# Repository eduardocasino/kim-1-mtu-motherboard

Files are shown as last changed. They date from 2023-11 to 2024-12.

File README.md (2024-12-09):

# KIM-1 Motherboard for MTU Cards

## **WARNING**

**ALTHOUGH THE CARDS HAVE BEEN TESTED NOW, THERE MAY BE MORE ERRORS. USE AT YOUR OWN RISK!!!**

If you ordered the first revision PCB, please see the "Rev. 1 Fix" section below.

If you ordered earlier revisions of the aux cards (RS-232 and USB), please see the "Aux. Cards Fix" section below. 

## **UPDATE**

There is now a third auxiliary card option, for connecting the KIM-1 terminal wirelessly using an ESP8266. This new board is not affected by the problems referred above.

This card requires to transfer its firmware to the ESP8266. [Please, see the set up instructions here](https://github.com/eduardocasino/kim-1-mtu-motherboard/blob/main/kim-1-aux-card-esp/README.md)

## About

Welcome to my KIM-1 Motherboardfor MTU cards repository.

This board follows the MTU standard for the KIM-1 expansion and application buses and enables to connect up to five cards, like the [K-1008](https://github.com/eduardocasino/k-1008-visable-memory-card-replica). All the CPU lines are buffered. Additionally, all signals of the KIM-1 ports are replicated on corresponding edge connectors to allow further expansions.

Two audio jacks allow for cassette deck connection and two optional daughterboards provide IEC and RS-232 or USB serial connections, and also a connector compatible with Corsham's SD Shield.

The MTU bus connects 1 to 1 to the KIM-1 expansion connector with the exception of pins 2,3, 16, 17, 18, 19, 20 and X, because MTU boards use some of these pins for power and expanded 18 bit address bus (See page 33 of the [MTU Fall 1980 6502 Peripherals and Software catalog](hhttp://retro.hansotten.nl/6502-sbc/mtu/) Lines 19 and 20 are connected to pins J (K7) and K (DECODE ENABLE) of the KIM-1 application connector, respectively. Those two signals can be limited to just the first or the first and second connectors by opening some jumpers.

A five screw terminal block provides power connections for both the KIM-1 (GND, +5V and +12V regulated) and the expansion boards (+7.5V and +16V unregulated). 

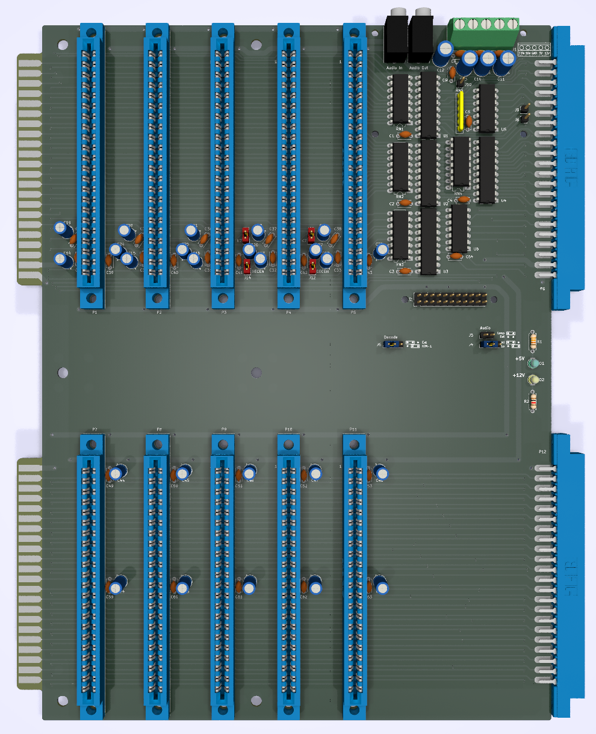
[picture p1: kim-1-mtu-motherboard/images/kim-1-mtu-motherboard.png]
components

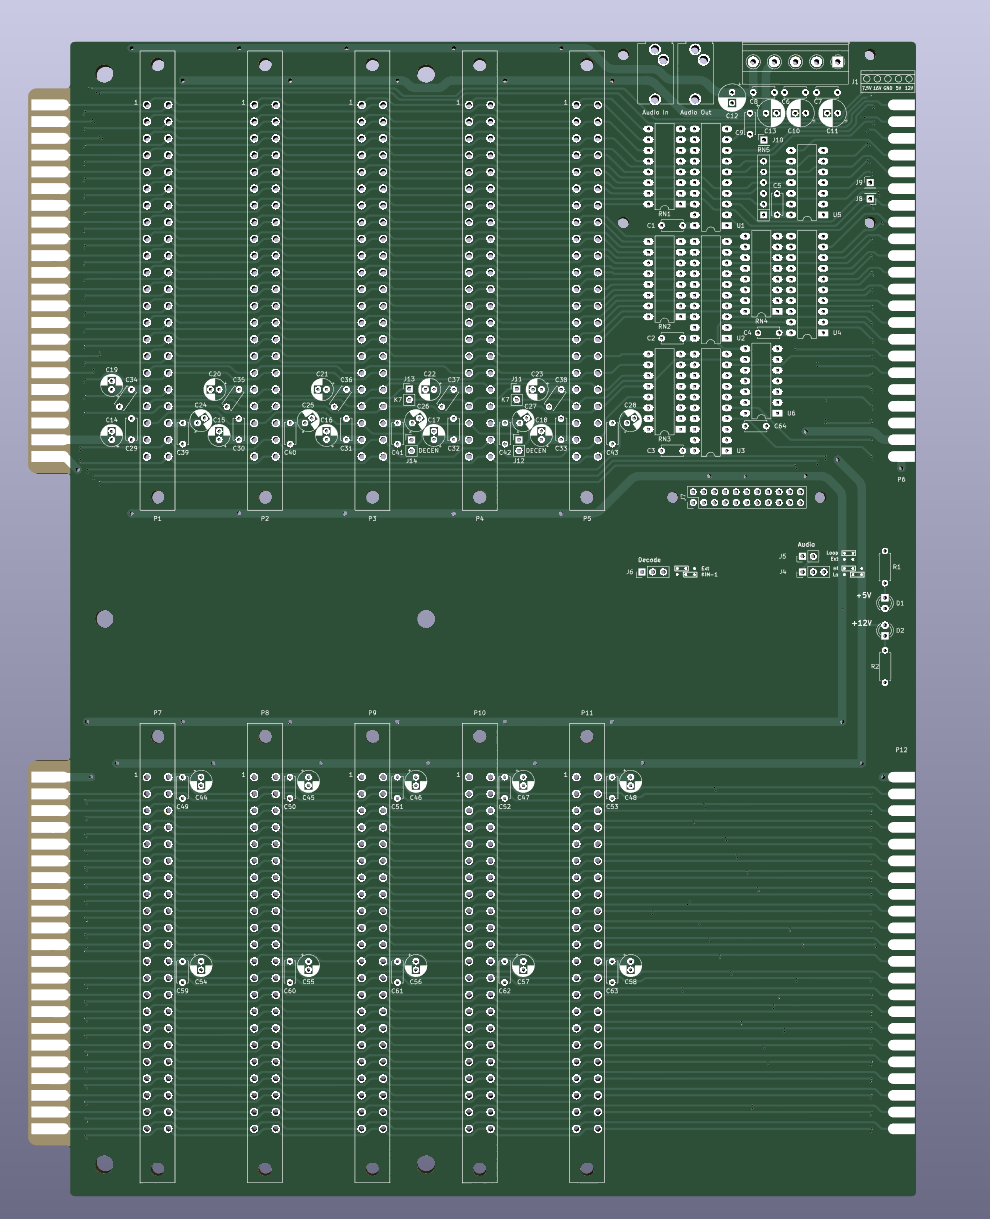
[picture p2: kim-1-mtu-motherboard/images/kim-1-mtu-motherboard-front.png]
front

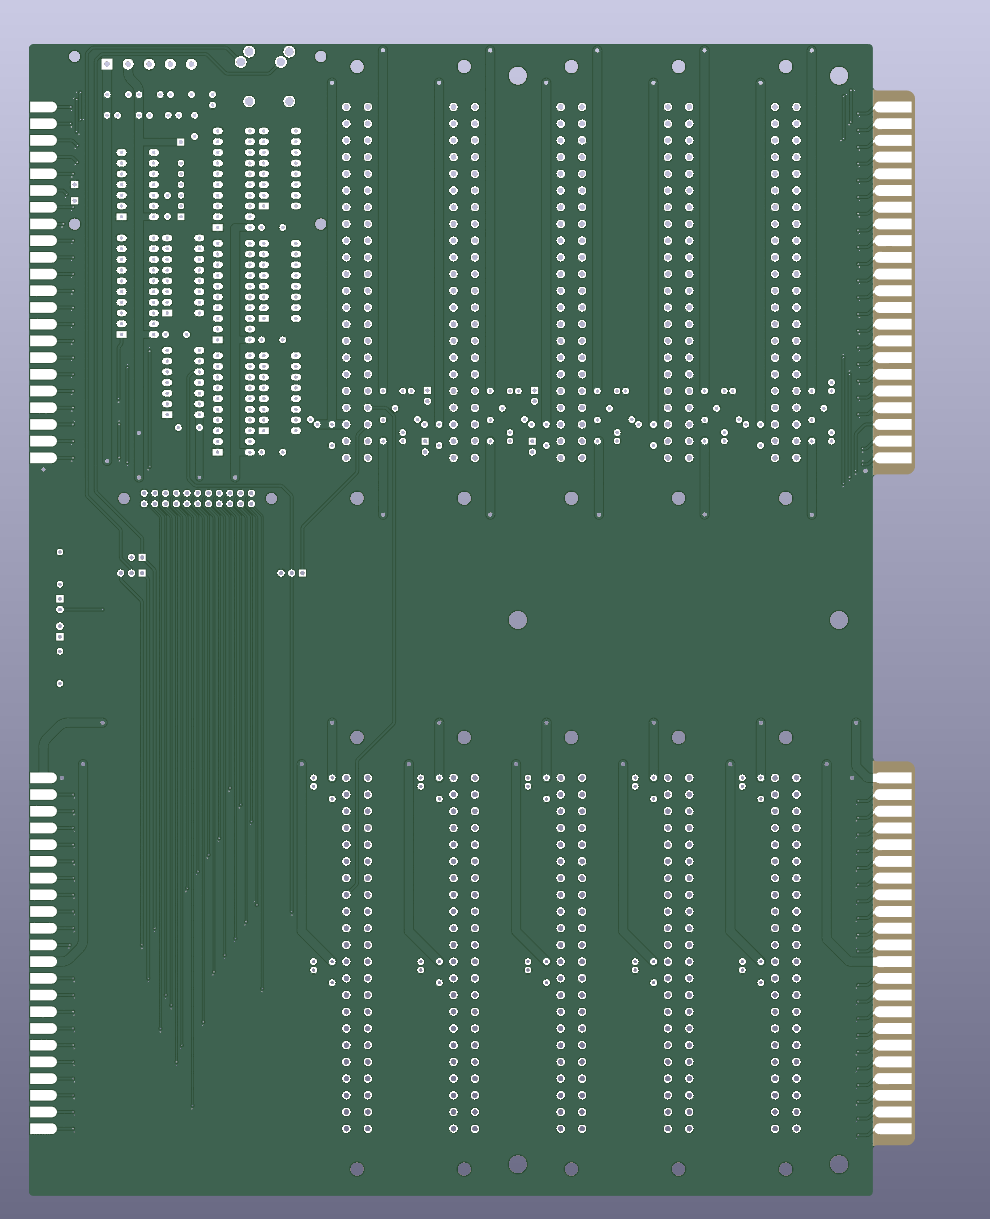
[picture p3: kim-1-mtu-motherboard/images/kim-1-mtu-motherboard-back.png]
back


Detail of the two auxiliary boards:
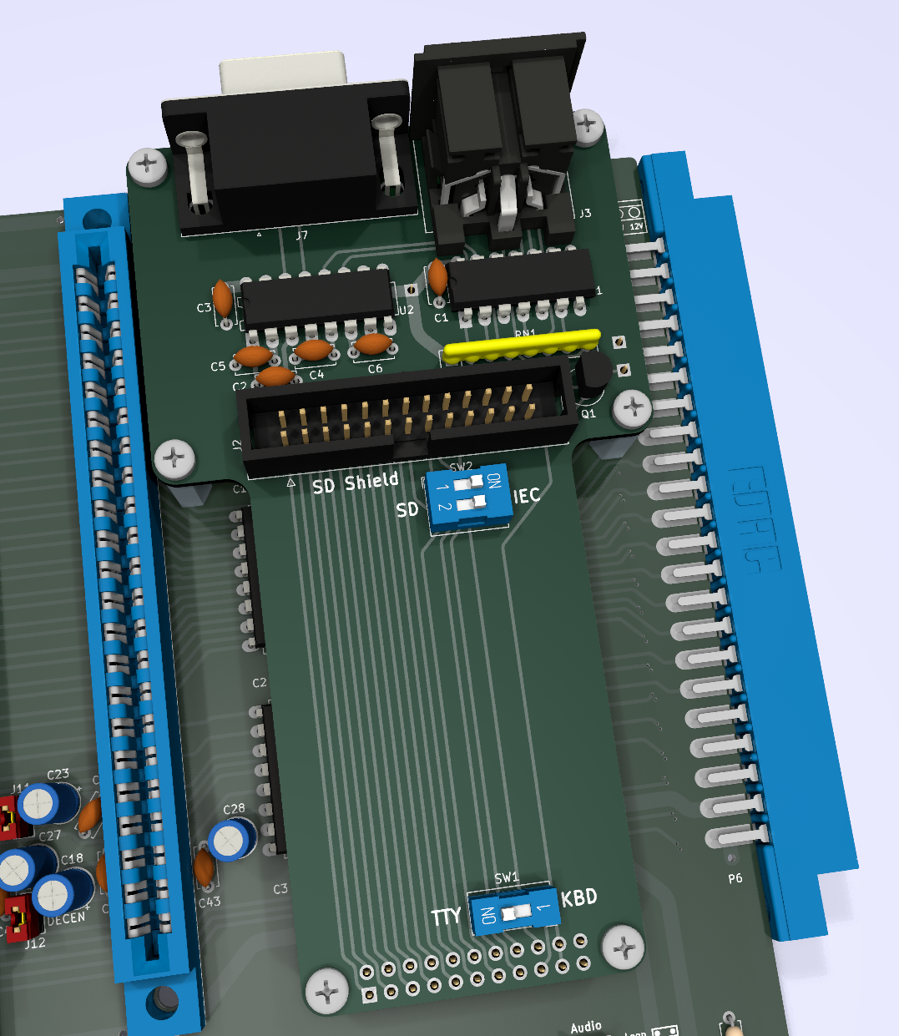
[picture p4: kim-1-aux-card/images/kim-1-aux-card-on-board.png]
rs232

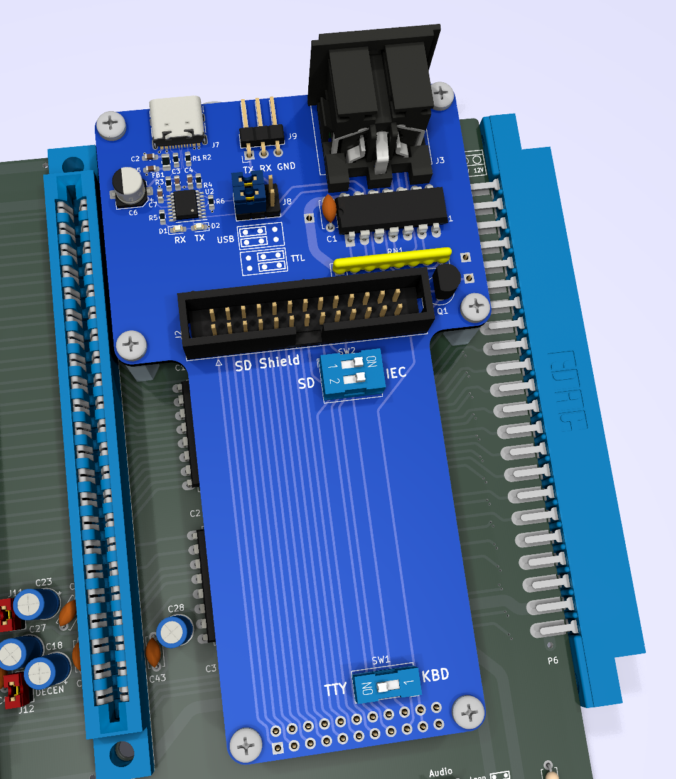
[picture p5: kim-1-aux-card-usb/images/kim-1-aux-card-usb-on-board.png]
usb


This is how an example setup with one K-1008 board and a [RAM/ROM expansion card](https://github.com/eduardocasino/kim-1-mtu-ram-rom) would look like:

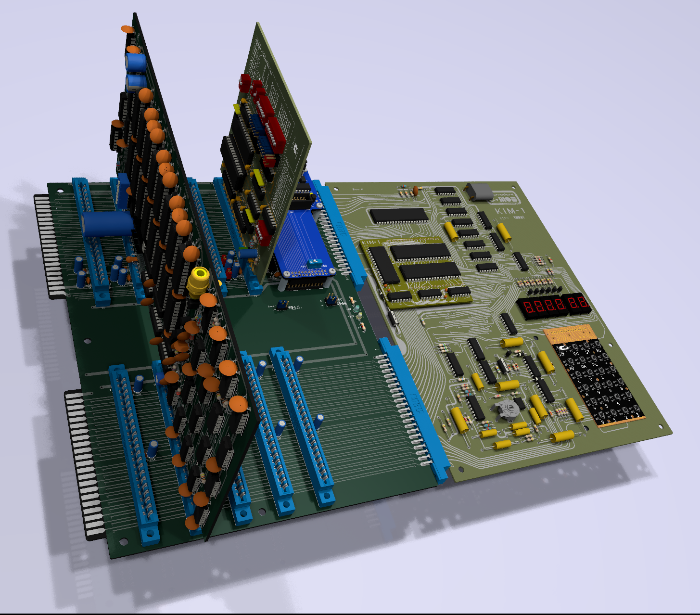
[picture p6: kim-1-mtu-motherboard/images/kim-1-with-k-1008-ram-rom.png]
setup


**NOTE**: [This expansion board is a much simpler option](https://github.com/eduardocasino/kim-1-mtu-expansion-card) if you just need to connect some MTU cards. Those are engineered so they put less than 1 TTL load on the CPU buses, so no buffering is really needed. Why the buffering, then? Well, just for fun.

## Licensing

This is a personal project that I am sharing in case it is of interest to any retrocomputing enthusiast and all the information in this repository is provided "as is", without warranty of any kind. I am not liable for any damages that may occur, whether it be to individuals, objects, KIM-1 computers, kittens or any other pets.



This work is licensed under a [Creative Commons Attribution-ShareAlike 4.0 International License](http://creativecommons.org/licenses/by-sa/4.0/).

See the LICENSE.md file for details.

## Rev. 1 Fix

If you tried to build revision 1 of this board, you found out that it does not work (See [Issue #2](https://github.com/eduardocasino/kim-1-mtu-motherboard/issues/2))

You can [install this simple PCB](https://github.com/eduardocasino/kim-1-mtu-motherboard/rev-1-fix) or, alternatively, perform this bodge on the back of the PCB:

Using a cutter, carefully cut these two spokes at pin 19 of U4:

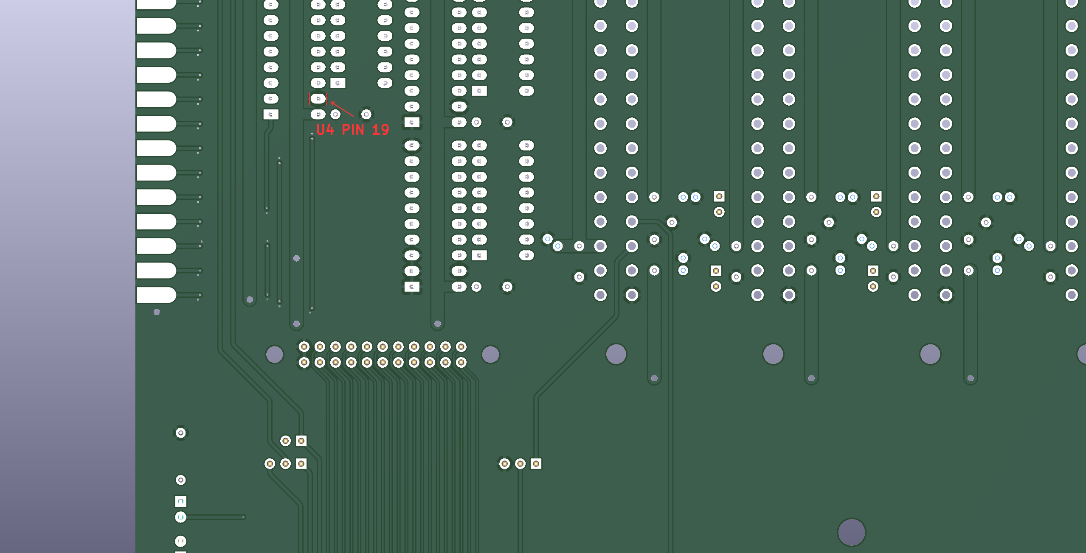
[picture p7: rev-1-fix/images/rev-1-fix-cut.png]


Grab a 14 pin IC socket with flat pins. Bend pins 1,2,3,7 and 14 outwards and cut the rest.

Solder wires to the pins as per this image:

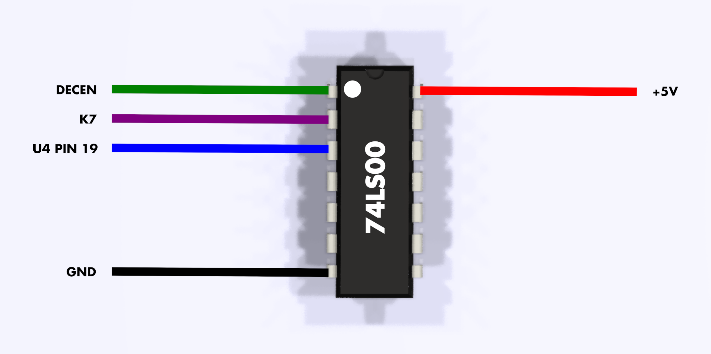
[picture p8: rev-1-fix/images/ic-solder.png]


Cover the back of the socket with non conductive tape. Attach the wires to these spots on the motherboard:

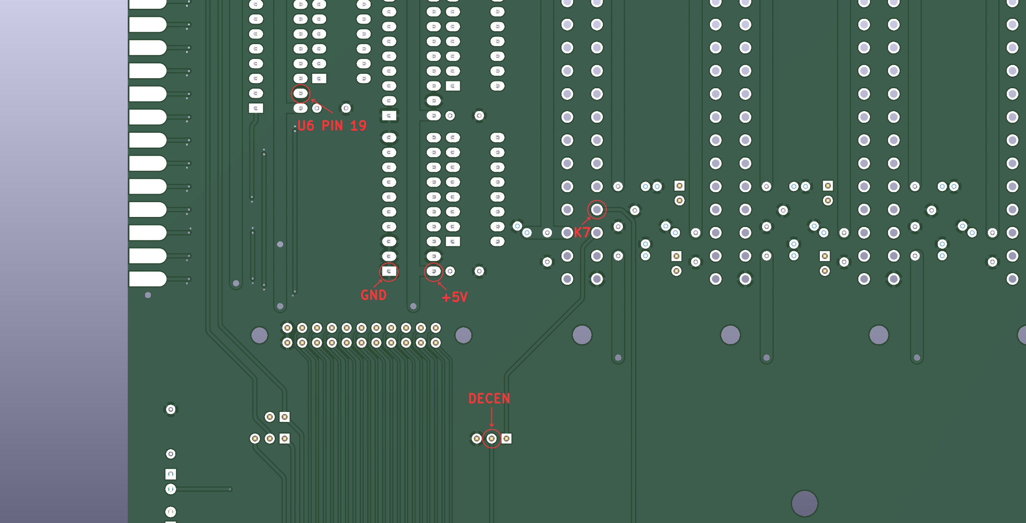
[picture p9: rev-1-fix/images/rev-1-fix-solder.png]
step2


Place a 74LS00 in the socket (check the orientation!) and fix evrything to the PCB using some tape, like in this image. I took K7 from another pin, but it is all the same:

step2

## Aux. Cards Fix

If you tried to build earlier revisions of the auxiliary boards (both RS-232 and USB), you may have found out that they do not work with Corsham's SD Shield, although they work fine with IEC disks (See [Issue #3](https://github.com/eduardocasino/kim-1-mtu-motherboard/issues/3))

If you need them to work with the SD Shield, you can perform this simple fix. **WARNING: Doing so, the cards will no longer work with IEC disks**

The fix is the same for both cards. Using a cutter, carefully cut these two tracks:

aux-card-fix

## Changelog
#### 17/02/2024
* Release Rev. 3 (fixes the auxiliary cards, the motherboard is unchanged)
* IEC socket footprint also supports Commodore-style sockets
* Add instructions to fix original auxiliary boards so they work with IEC disks.

#### 21/01/2024
* Release Rev. 2
* Add instructions to fix Rev. 1 boards.

#### 03/01/2024
* Minor silkscreen update

#### 02/01/2024
* Disable data bus transceiver when DECEN or K7 are active (low)

## Acknowledgements

* Hans Otten and his [Retro Computing blog](http://retro.hansotten.nl/). Documentation of MTU's line of hardware expansions for the KIM-1

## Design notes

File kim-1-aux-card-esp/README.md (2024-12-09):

## Wireless terminal board

This design is based on a setup by Ryan Roth, mentioned in this [Google Groups thread](https://groups.google.com/g/pal6502/c/w8N0uSgJXQY), and the ESP8266 needs to be [programmed with his firmware](https://github.com/ryaneroth/ESP8266-SerialTelnet). For convenience, I keep a [copy of his repo here](https://github.com/eduardocasino/ESP8266-SerialTelnet).

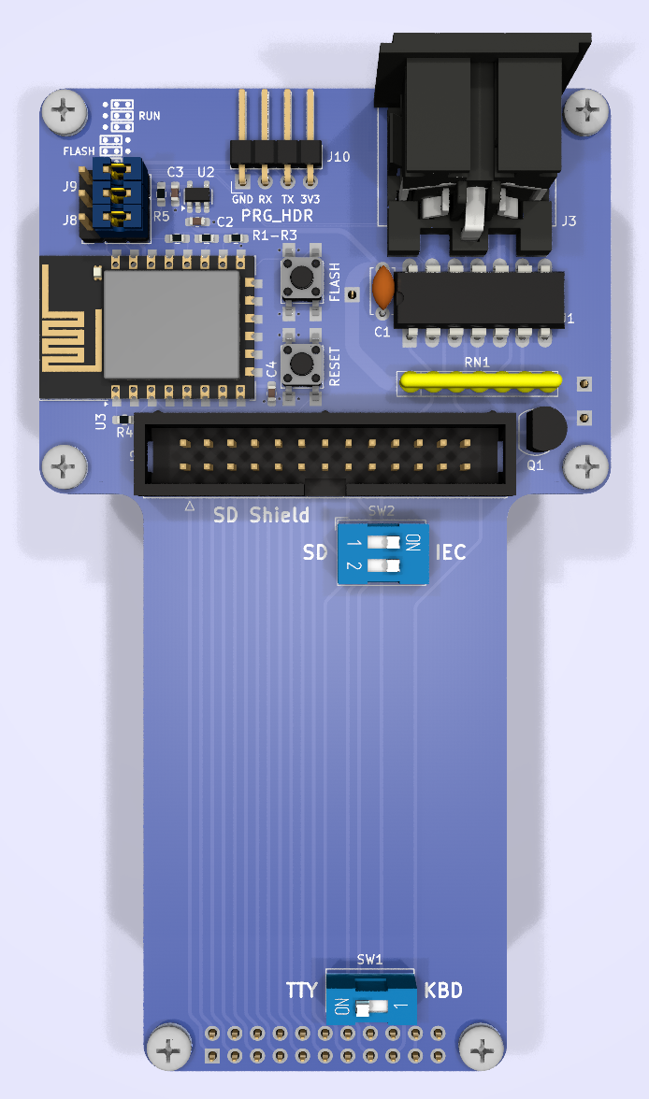
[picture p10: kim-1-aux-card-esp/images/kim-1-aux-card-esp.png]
WiFi auxiliary board


## Firmware install instructions

1. Download and install the latest **Arduino IDE 2.X (preferred) or 1.6.X** from [https://www.arduino.cc/en/Main/Software](https://www.arduino.cc/en/Main/Software)

2. Install **ESP8266** Arduino support using Boards Manager: [https://github.com/esp8266/Arduino#installing-with-boards-manager](https://github.com/esp8266/Arduino#installing-with-boards-manager)

    ***Only*** for IDE 1.6.X, force install version >= 2.4.0. Replace package URL with: [https://github.com/esp8266/Arduino/releases/download/2.4.0-rc1/package_esp8266com_index.json](https://github.com/esp8266/Arduino/releases/download/2.4.0-rc1/package_esp8266com_index.json)

3. Install Install the following libraries:
    * WifiManager: [https://github.com/tzapu/WiFiManager#install-through-library-manager](https://github.com/tzapu/WiFiManager#install-through-library-manager)

4. Put the three bridges in the "**FLASH**" position and connect the board to your computer using an USB to serial adapter.

5. Select board `Generic ESP8266Module`

6. Upload the Sketch contained in `telnetserver` folder from the [ESP8266-SerialTelnet](https://github.com/eduardocasino/ESP8266-SerialTelnet) repo.

7. The moment the `Connecting...` message appears in the console, press the "**RESET**" button and, while holding it", press momentarily the "**FLASH**" button. Then, release the "**RESET**" button. Wait until the sketch is uploaded.

8. Connect to the ESP8266 WiFi network and go to "http://192.168.4.1". Configure connection to your AP, set password, then switch back to your local wifi

9. Disconnect the card and put the bridges back to the "**RUN**" position. Now, you can install it into the motherboard.

10. Connect to the ESP8266 using a Telnet client. Set local echo to off.

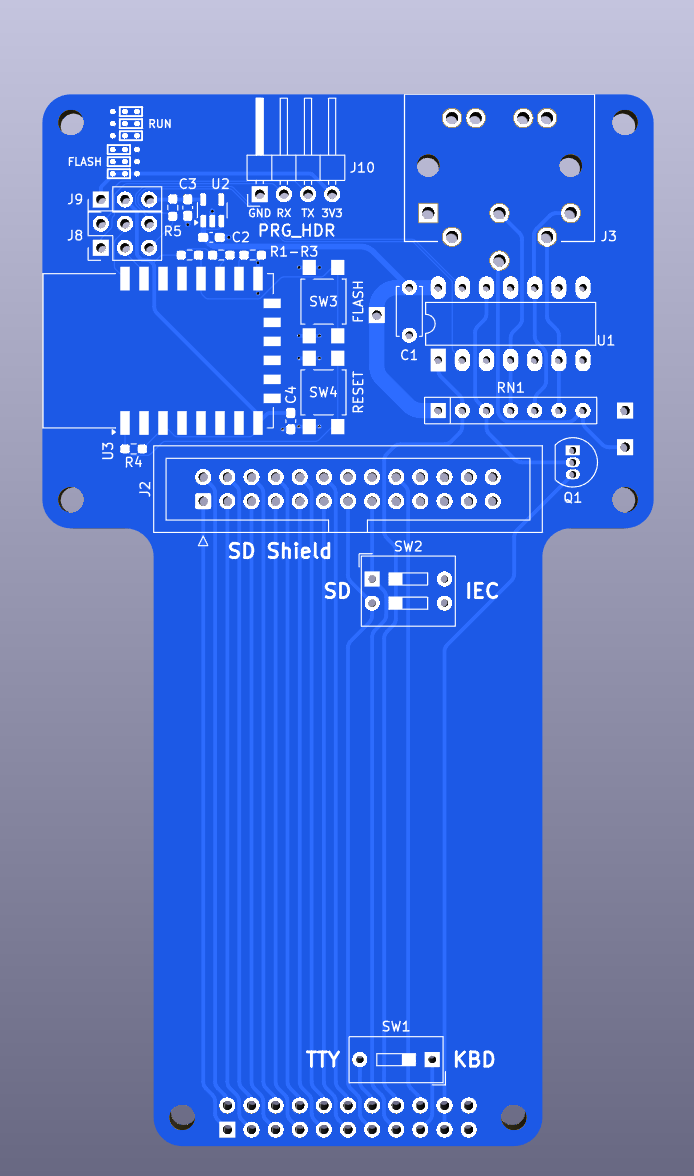
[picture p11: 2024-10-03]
kim-1-aux-card-esp/images/kim-1-aux-card-esp-front.png

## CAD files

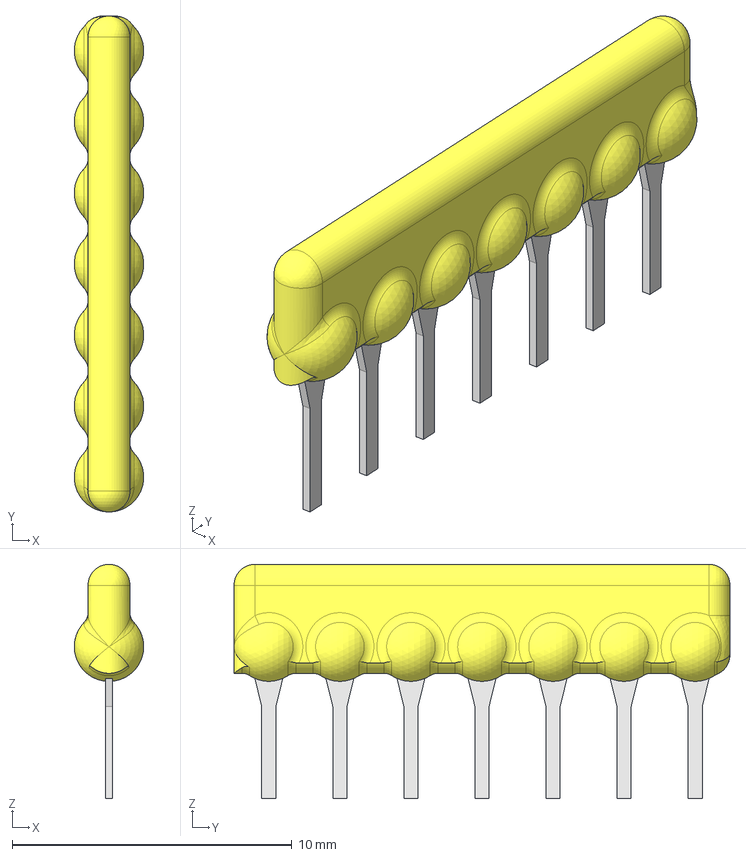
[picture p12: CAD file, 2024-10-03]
kim-1-aux-card-esp/3dmodels/4607x.stp
2.48 x 17.7 x 8.38 mm

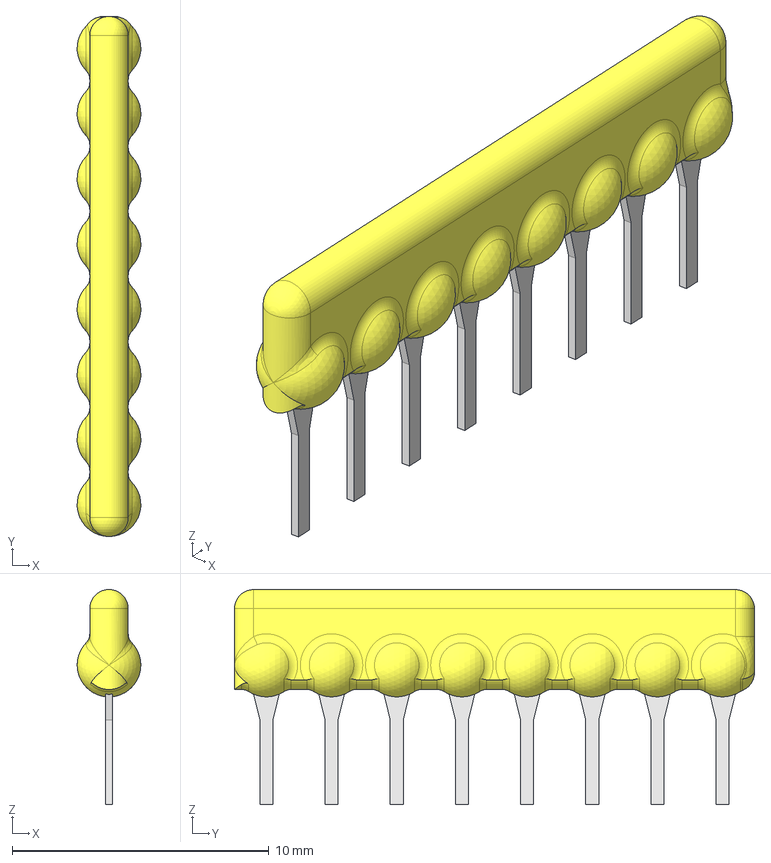
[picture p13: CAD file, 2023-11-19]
kim-1-aux-card-usb/3dmodels/4608x.stp
2.48 x 20.3 x 8.38 mm

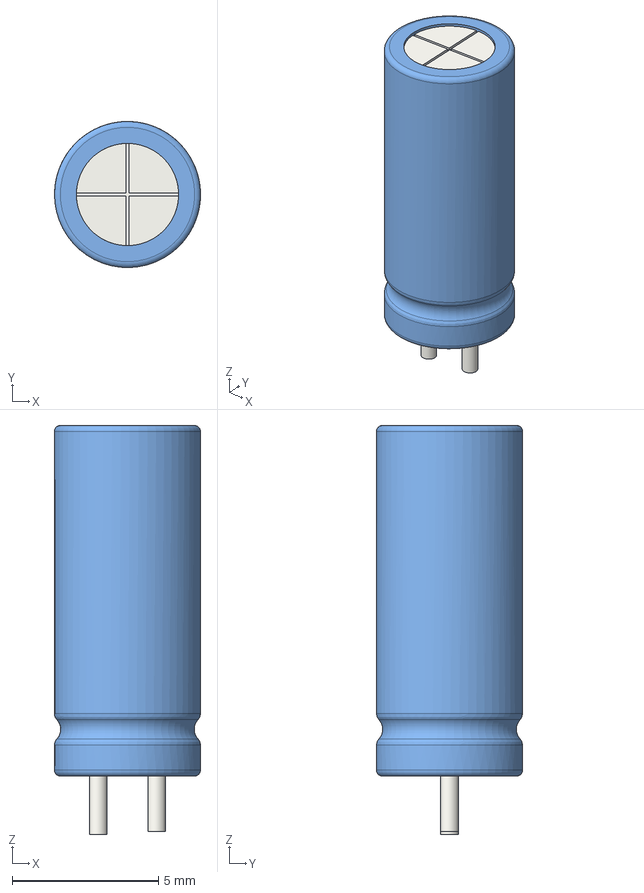
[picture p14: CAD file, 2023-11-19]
kim-1-mtu-motherboard/3dmodels/C_Radial_D5.0mm_H12.0mm_P2.00mm.step
5.00 x 5.00 x 14.0 mm
38c14877-72a4-11ee-ae0a-535837699564_part
38c14878-72a4-11ee-ae0a-535837699564_part
38c14879-72a4-11ee-ae0a-535837699564_part
38c1487a-72a4-11ee-ae0a-535837699564_part
38c1487b-72a4-11ee-ae0a-535837699564_part

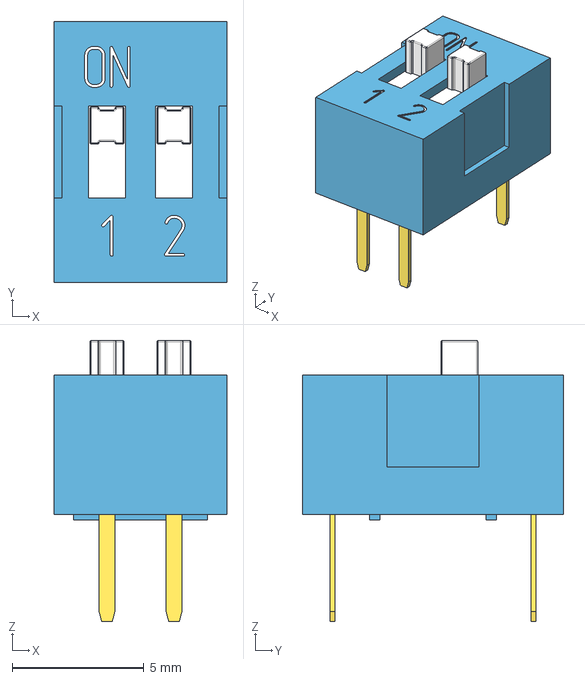
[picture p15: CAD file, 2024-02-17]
kim-1-aux-card-esp/3dmodels/DS1040-02 (DIP_switch) blue.stp
6.54 x 9.90 x 10.7 mm

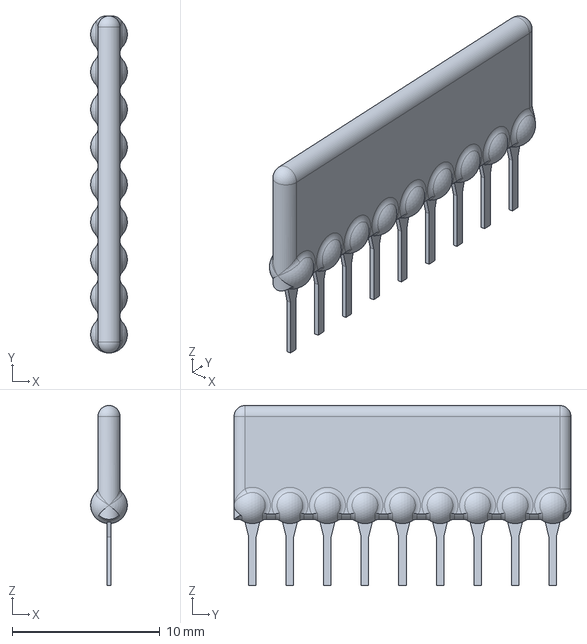
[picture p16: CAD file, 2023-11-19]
kim-1-mtu-motherboard/3dmodels/resistor_array_8.step
2.48 x 22.8 x 12.2 mm

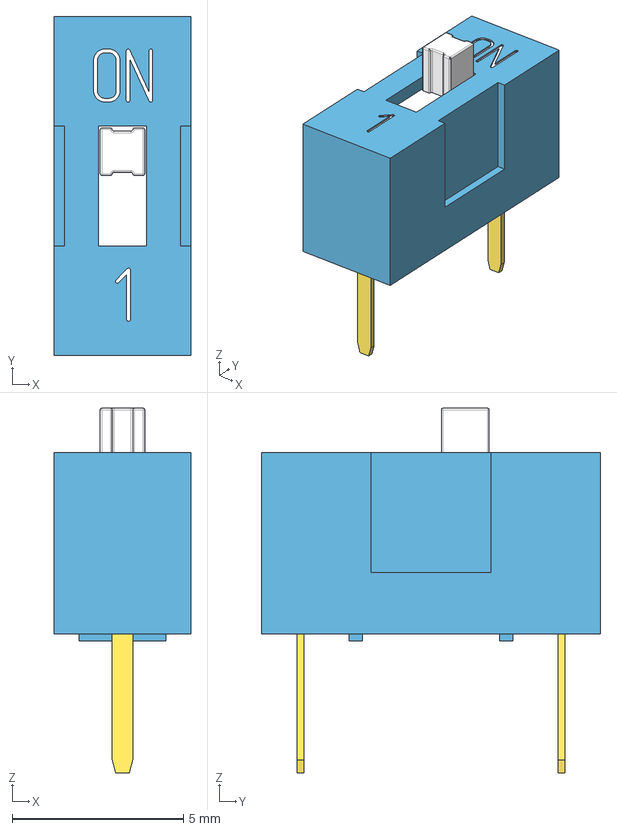
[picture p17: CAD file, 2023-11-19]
kim-1-aux-card-esp/3dmodels/DS1040-01 (DIP_switch) blue.stp
4.00 x 9.90 x 10.7 mm

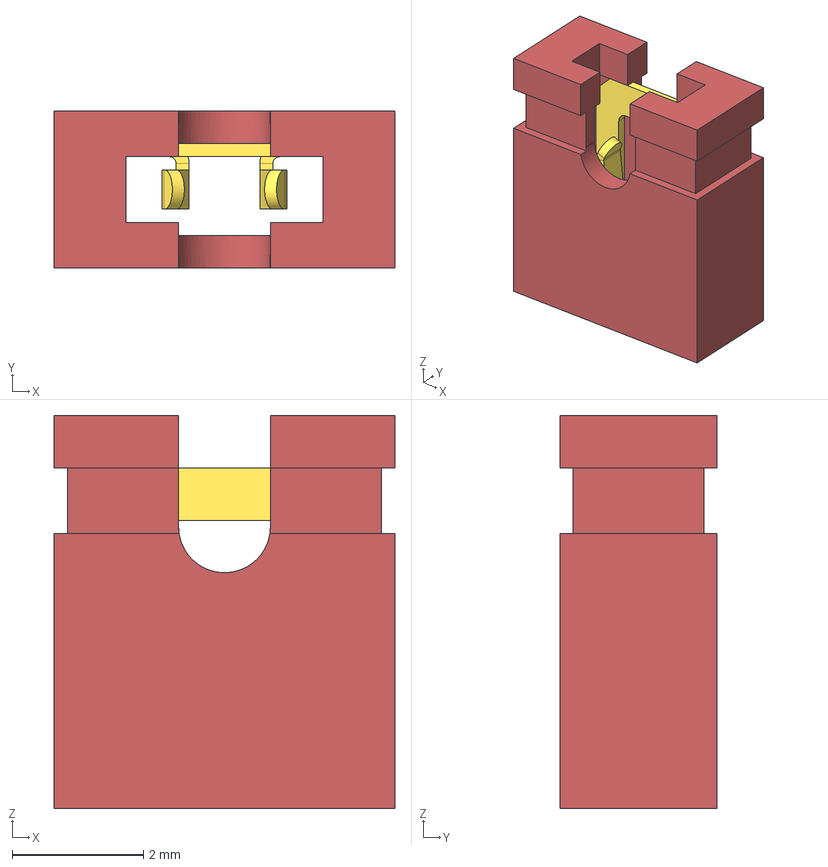
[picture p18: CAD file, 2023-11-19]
kim-1-mtu-motherboard/3dmodels/Jumper-red.step
5.20 x 2.40 x 6.00 mm

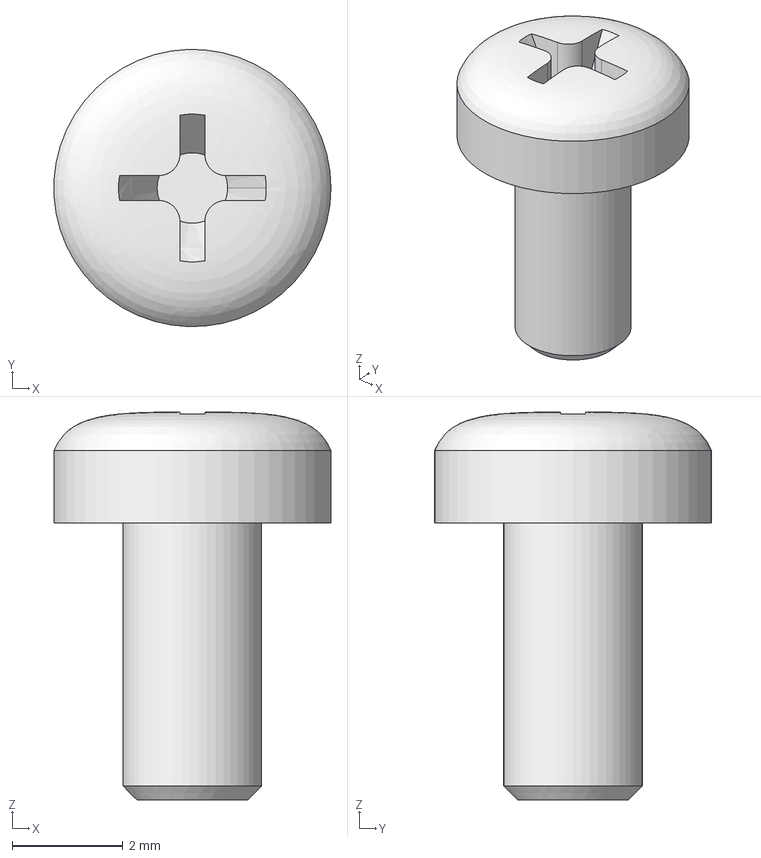
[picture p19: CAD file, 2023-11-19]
kim-1-aux-card-esp/3dmodels/cross_recessed_phillips_pan_head_M2.5x05.step
5.00 x 5.00 x 7.00 mm

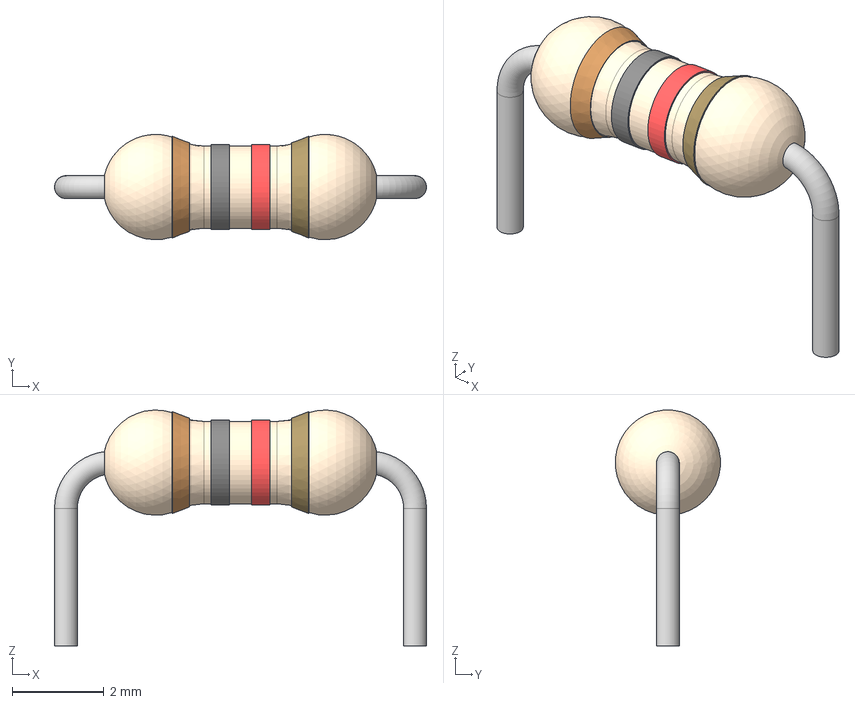
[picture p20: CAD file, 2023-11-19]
kim-1-mtu-motherboard/3dmodels/res-1_4w-1K.step
8.12 x 2.29 x 5.14 mm
Resistor-body
Ring-1
Ring-2
Ring-3
Ring-4
pins

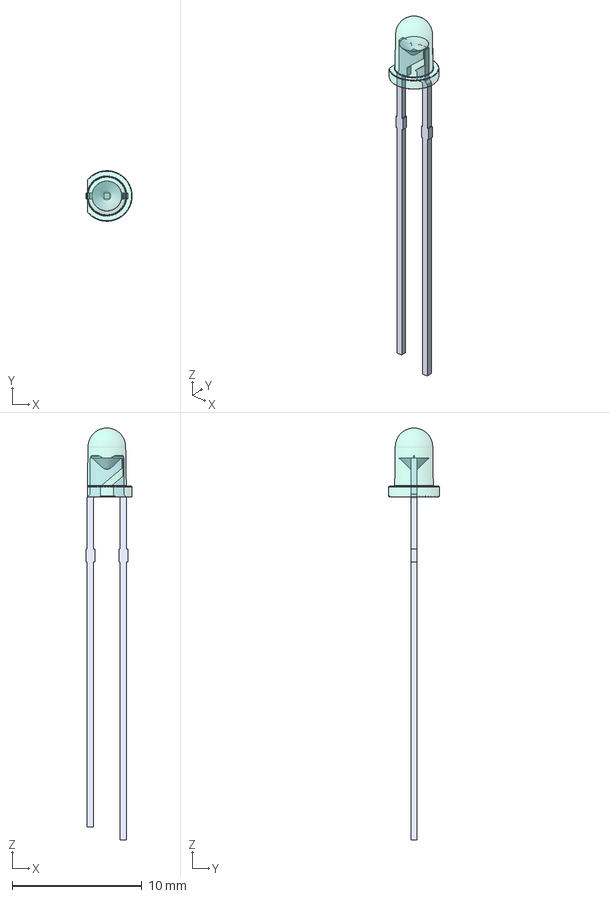
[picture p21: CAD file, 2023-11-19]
kim-1-mtu-motherboard/3dmodels/LED D3 - Green-Clear.step
3.57 x 3.90 x 31.7 mm

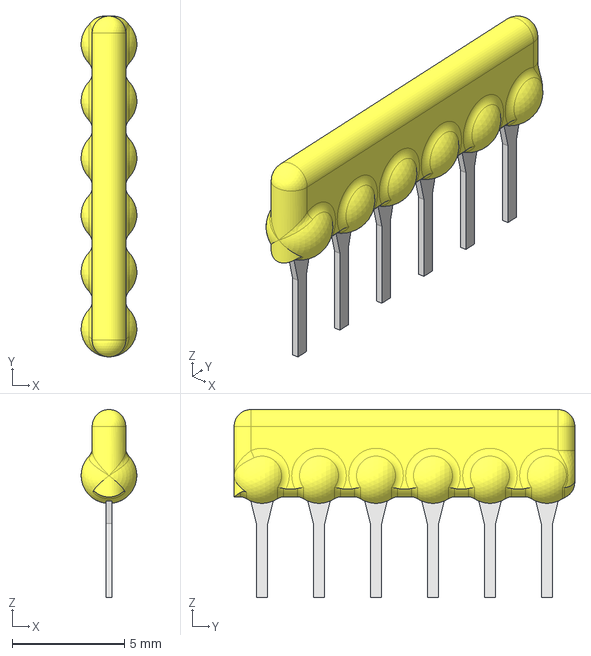
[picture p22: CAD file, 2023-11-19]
kim-1-mtu-motherboard/3dmodels/resistor_array_5.step
2.48 x 15.2 x 8.38 mm

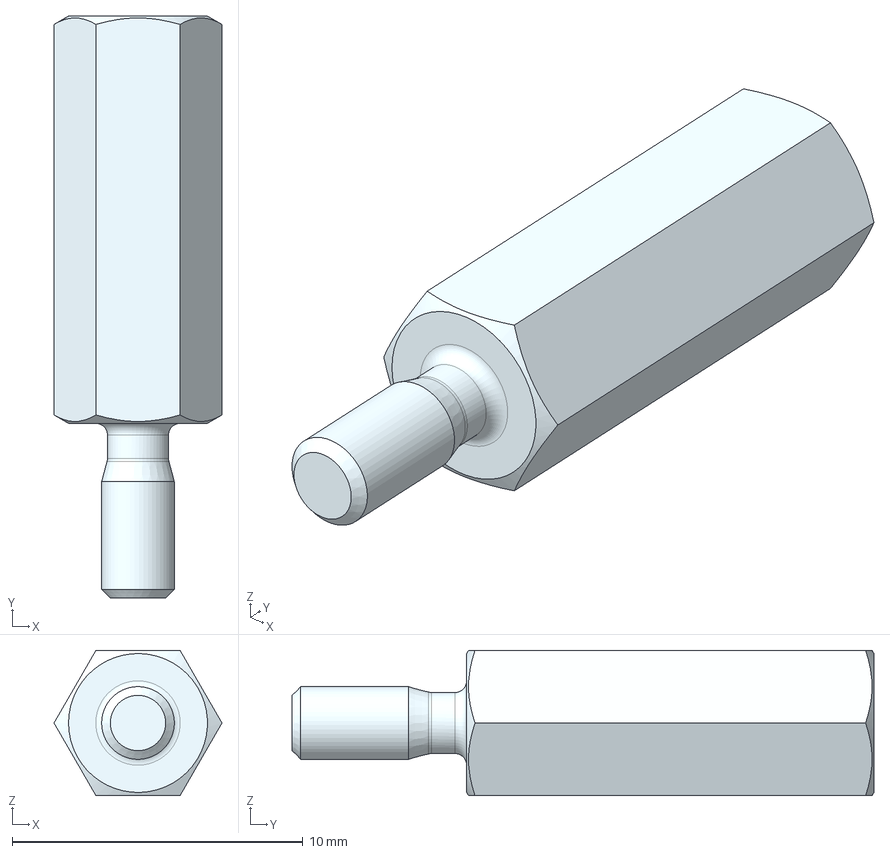
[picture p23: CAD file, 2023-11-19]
kim-1-aux-card-esp/3dmodels/Abstandzbolzen Stahl verzinkt I-A M2.5_-_Ettinger - 5.12.141 (M2,5x14).stp
5.77 x 20.0 x 5.00 mm

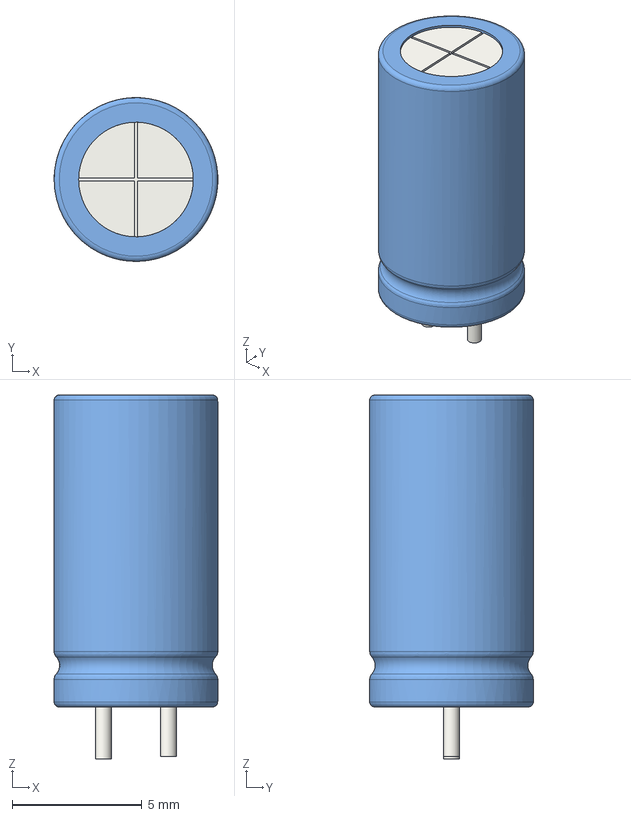
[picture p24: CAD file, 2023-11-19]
kim-1-mtu-motherboard/3dmodels/C_Radial_D6.3mm_H12.0mm_P2.50mm.step
6.30 x 6.30 x 14.0 mm
02c9364b-712a-11ee-b682-09d101288ea8_part
02c9364c-712a-11ee-b682-09d101288ea8_part
02c9364d-712a-11ee-b682-09d101288ea8_part
02c9364e-712a-11ee-b682-09d101288ea8_part
02c9364f-712a-11ee-b682-09d101288ea8_part

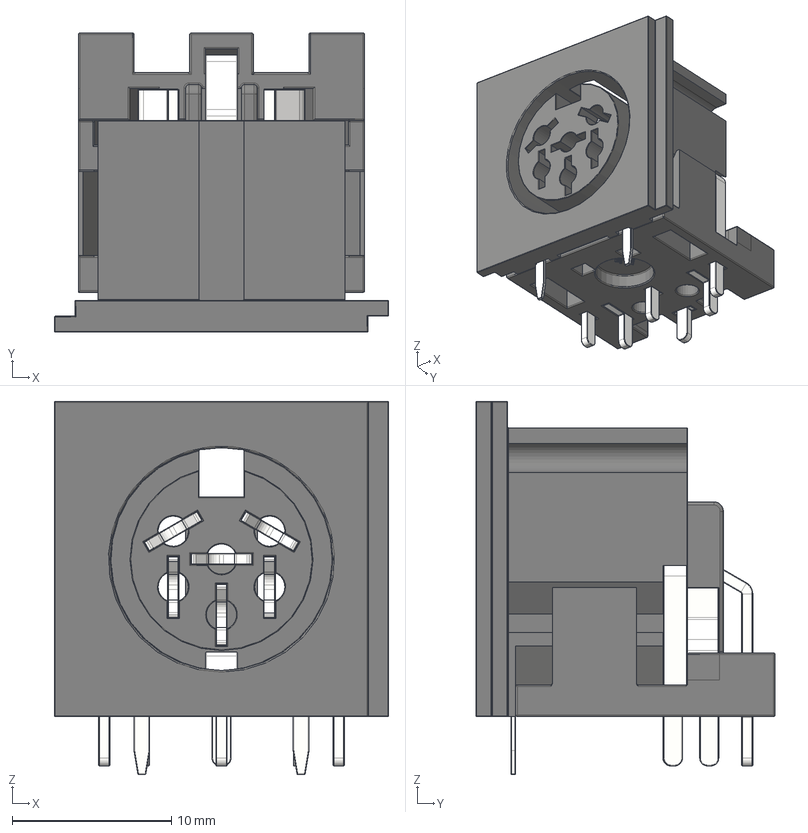
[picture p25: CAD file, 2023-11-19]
kim-1-aux-card-esp/3dmodels/DIN 45322 C64 IEC serial port.step
21.0 x 18.8 x 23.4 mm
Baseplate IEC
Pin3
Pin4_2
Pin5_1
Pin6
Gnd pins
Housing

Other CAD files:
kim-1-aux-card-esp/3dmodels/Jumper-blue.step
kim-1-mtu-motherboard/3dmodels/res-1_4w-330R.step
kim-1-mtu-motherboard/3dmodels/LED D3 - Yellow-Clear.step

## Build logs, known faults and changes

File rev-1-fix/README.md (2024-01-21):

# Fix for KIM-1 Motherboard

## **WARNING**

**ALTHOUGH THIS FIX SEEMS TO BE WORKING SO FAR, IT STILL NEEDS MORE TESTING. USE AT YOUR OWN RISK!!!**

## About

This simple PCB fixes the first revision of the KIM-1 motherboard. Just put it in place of U4 and follow the install instructions.

(See [Issue #2](https://github.com/eduardocasino/kim-1-mtu-motherboard/issues/2))

**NOTE: This is only necessary for the first revision of the motherboard. Rev. 2 is already corrected.**

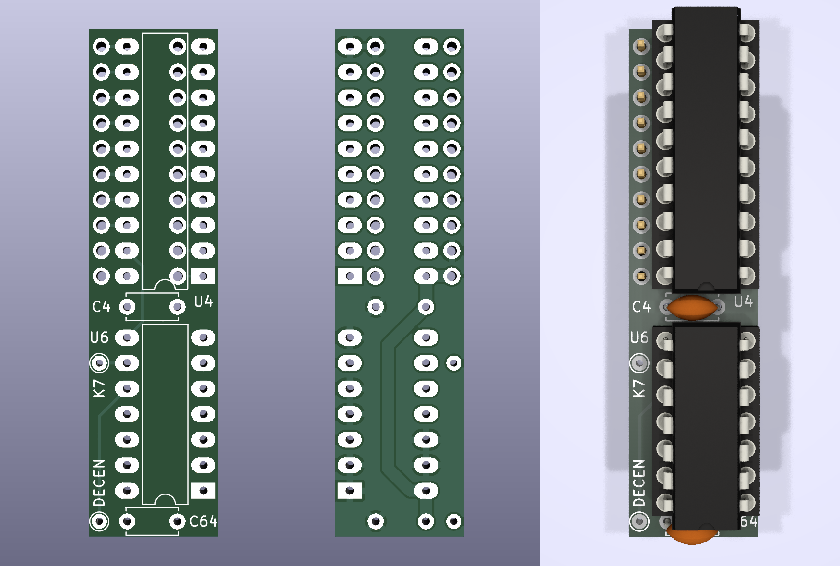
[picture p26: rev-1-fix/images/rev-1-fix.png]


## Installation

Carefully drill a 2mm hole in this position:

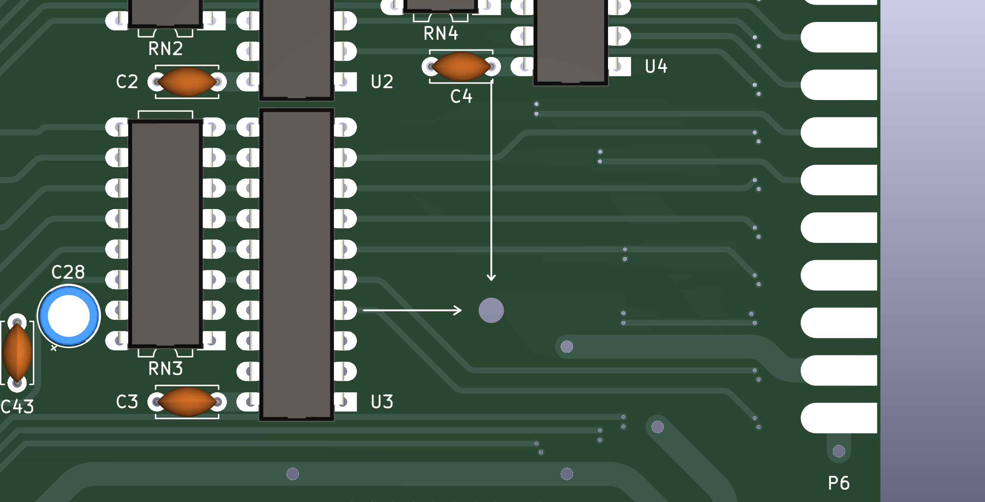
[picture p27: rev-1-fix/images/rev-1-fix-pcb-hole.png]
step1


Solder sufficiently long cables to K7 and DECEN pads of the fix board.

Remove C4 and place the fix board in place of U4. Pass the cables through the newly drilled hole.

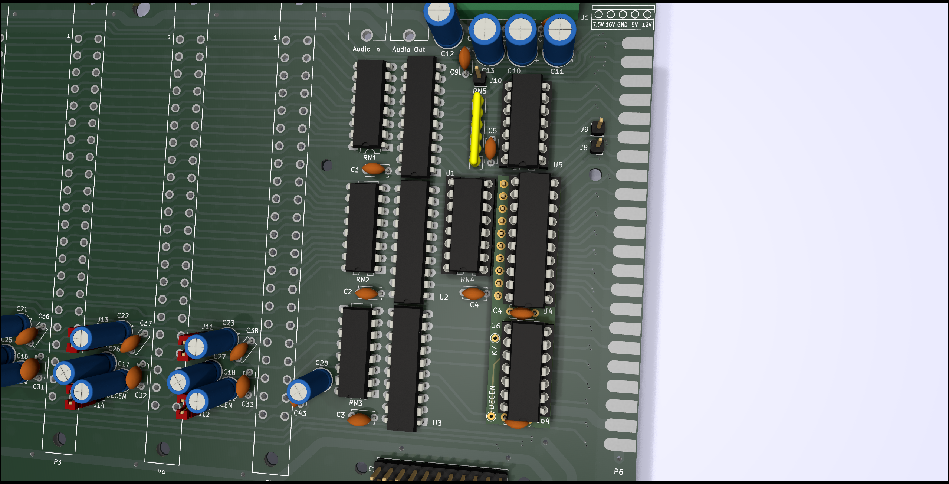
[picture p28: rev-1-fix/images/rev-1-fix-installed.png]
step2


Solder the cables to the back of the motherboard at these spots:

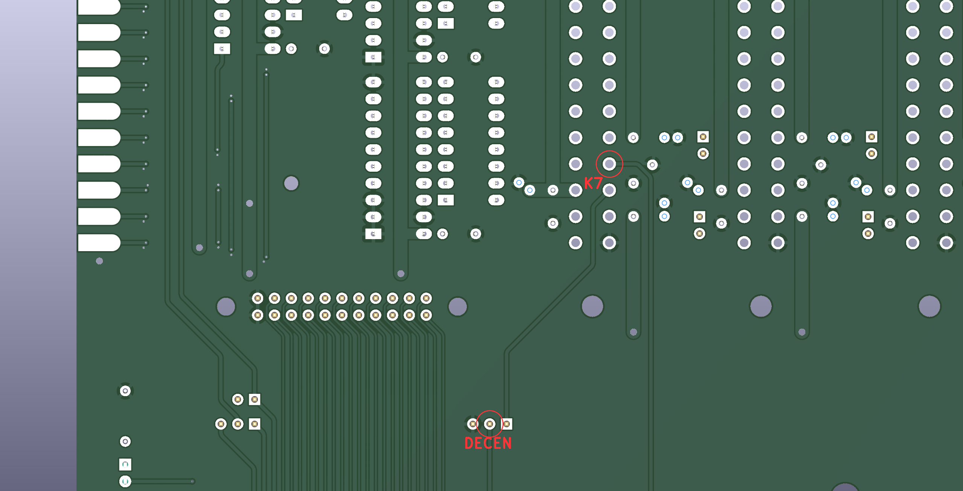
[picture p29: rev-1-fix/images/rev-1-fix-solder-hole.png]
step3


## Licensing

This is a personal project that I am sharing in case it is of interest to any retrocomputing enthusiast and all the information in this repository is provided "as is", without warranty of any kind. I am not liable for any damages that may occur, whether it be to individuals, objects, KIM-1 computers, kittens or any other pets.



This work is licensed under a [Creative Commons Attribution-ShareAlike 4.0 International License](http://creativecommons.org/licenses/by-sa/4.0/).

See the LICENSE.md file for details.

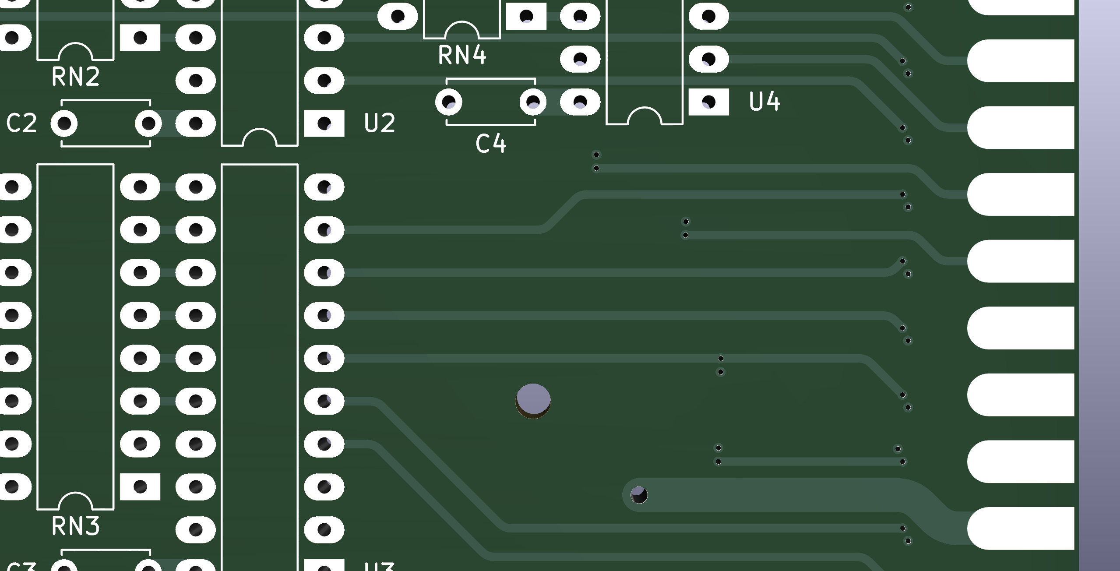
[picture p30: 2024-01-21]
rev-1-fix/images/rev-1-fix-drill.png

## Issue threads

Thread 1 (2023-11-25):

Right angle expansion connector

ryaneroth, 2023-11-25:
Have you considered making the expansion connector a right angle connector like the rest on the board, so you could install this in a chassis like Dave's? https://www.youtube.com/watch?v=fMxOWngmy8I

eduardocasino, 2023-11-25:
Not really. This is meant for a "tabletop" system, like the KIM-4 or the KIMSI.

Anyway, if you are planning to design a chassis for a KIM-1 system, let me know and I can certainly design a backplane for it!

ryaneroth, 2023-11-25:
Thank you for the offer, I may take you up on it. I have a friend that is a metal fabricator, and I will work with him on building a chassis.  Trying to find higher res images of the chassis Dave has, which looks similar to the one here http://retro.hansotten.nl/6502-sbc/kim-1-manuals-and-software/kim-1-related-hardware/the-computerist/

eduardocasino, 2023-11-25:
It is the K-1005 card file system. There is some info in page 35 of this document: http://www.6502.org/users/sjgray/computer/mtu/MTU-fall-1980.pdf

ryaneroth, 2023-12-22:
I just ended up buying 90 degree 44 pin edge connectors so I can mount the motherboard vertically. I had to order all the PCBs in quantities of 5, so if you are US based, I'd gladly send you one of the motherboards. I would also like to sell the rest of the PCBs (KIM-1, 6532 adapter, keypad, motherboard, visual memory, RAM/ROM board) online if that is OK with you.
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

eduardocasino, 2023-12-23:
Looks great. I assume your friend is building a chassis or you're going to have a hard time when you start connecting boards. :)

The motherboard and RAM/ROM are untested!!! I hope you read the warnings and that you ordered knowing what you were doing... My cards are still travelling from China, so I can't guarantee that they will work. At least I can see that the green led is glowing :P

Thanks for your offer, but I'm based in Spain. I don't mind that you sell your excess PCBs, with just a few conditions:

*  Do not sell the motherboard and RAM/ROM until they are tested **and confirmed working!**
*  Please provide links to the repositories in your selling ads
*  The K-1008, KIM-1, 6532 adapter and keypad boards have a **non-commercial license**, so please sell them at cost. The RAM/ROM and motherboard are Open Hardware, so this restriction does not apply but, **again, wait until they are confirmed working!**

ryaneroth, 2023-12-23:
Yeah, I'll be sketching up plans for a chassis shortly. I found some nice plastic guide rails to support the PCBs once in it.

lol, yeah I realize they are untested, but at least where I live, the boards are cheap to have made, it is the shipping that is most of the cost. So it was cheaper to just order the untested boards now, along side a different order, and take the risk, then to pay for separate shipping for them down the road.

My plan is to not sell anything until tested :)

I already offered up my spare KIM-1 boards in the PAL-1 user group **after** I completed my build, at cost plus shipping to the buyer, but then thought I should still run selling them by you to be safe: https://groups.google.com/g/pal6502/c/vnEvhhbyzWM

My goal is not to make a profit, but just to see the spare boards get into the hands of people who will use them.

eduardocasino, 2023-12-23:
> I'll update you with my build progress as it gets further along. I'm currently waiting on a few parts, but I did verify power and serial were passing through the motherboard, so that is something :)

Please do, that will spare me some troubleshooting :) I am also very interested to see how the chassis turns out.

> lol, yeah I realize they are untested, but at least where I live, the boards are cheap to have made, it is the shipping that is most of the cost. So it was cheaper to just order the untested boards now, along side a different order, and take the risk, then to pay for separate shipping for them down the road.

Same here. I hope I did not make any mistakes, anyway.

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

That is fantastic, thank you!

> Separate question; how hard is it to create a interactive BOM for all the different boards, I found it extremely useful while building the KIM-1?

Really easy, this plugin for KiCad does it all: https://github.com/openscopeproject/InteractiveHtmlBom

I was planning to add them once the builds were tested.

> Also, including links to part sources could be helpful for others, if you want to compile a list, I could provide links to the US based sources I used.

OK, will do. I source most of the parts from DigiKey, the rest from Aliexpress (things like switches, connectors or some passives, like resistors or ceramic caps, never ICs, transistors or non-ceramic)

ryaneroth, 2023-12-23:
Thanks for the KiCad plugin link!

I had good luck with DigiKey and Mouser for sourcing most of the parts, but here are links to a few parts that gave me trouble finding sources for:

1Mhz crystal
https://www.elexp.com/products/12c1mcrystal-1-mhz

7 segment LED
https://www.digikey.com/en/products/detail/nte-electronics-inc/NTE3061/11648117

SRAM
https://www.jameco.com/z/MM2102AN-4-National-Semiconductor-IC-MM2102AN-4-NMOS-SRAM-1024-Bit-1024x1-250ns-DIP-16_2287991.html
https://www.arcade-electronics.com/ProductDetails.asp?ProductCode=NTE-2102

Piher resistor
https://www.electronicsurplus.com/piher-5k043m-resistor-trimming-5k-ohm-package-of-5:

ryanrothsonos, 2023-12-30:
Just a status update:

1) If I have the 74LS245 installed in the motherboard, my KIM-1 becomes unresponsive
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
ryaneroth, 2024-02-10:
Progress! I think I cleaned up any shorts, and I can write to memory now.  I am running glitchwork's memory test right now to make sure my memory is good (or that there aren't anymore shorts)
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

eduardocasino, 2024-02-10:
Does this happen for the full 8k range?

ryaneroth, 2024-02-10:
It would appear so

eduardocasino, 2024-02-10:
OK, inspecting the schematic, these seem the faulty chips:

D00D:FE -> ODD, bit 0  --> U42
C001:BF -> ODD, bit 6  --> U37
C008:BF -> EVEN, bit 6 --> U22
C009:3F -> ODD,  bits 7, 6 --> U36, U37
D005:7F -> ODD,  bit 7, --> U36
D00D:1E -> ODD, bits 7, 6, 5, 0 --> U36, U37, U38, U42

So it seems that memory chips U22, U36, U37, U38 and U42 may be faulty

ryaneroth, 2024-02-10:
I actually think it is around refreshing the DRAM as if I manually keep reading an address it will hold the correct value

ryaneroth, 2024-02-10:
OK, I think we are getting there 😆
```
C009 C9 89
C00B CB 8B
C00D CD 8D
C00F CF 8F
C019 D9 99
C01B DB 9B
C01D DD 9D
C01F DF 9F
```
If I am understanding the memory layout correctly, this would mean U37 if the problem chip, but I've replaced it with several chips, including known good ones, so I am guessing there is a connectivity issue, or short.

eduardocasino, 2024-02-10:
Congrats on your New k-1008!

Did you see my fix to the RAM/ROM board?

ryaneroth, 2024-02-11:
Ooh, I missed that somehow, thanks for the heads up

I can now fill the screen solid white or black, but it appears that whatever I enter gets repeated. The first image is at boot, the second image is after setting C000-C016 to FF. This doesn't seem like the correct behavior 😄
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

eduardocasino, 2024-02-11:
I would first look for shorts in the address lines

ryaneroth, 2024-02-11:
Just an update

1) I spent a solid hour with a microscope looking at traces, I think they are all good
2) I verified with a multimeter that there are no shorts on the address lines on the RAM side of the 74LS158s
3) I have verified that writing to addresses outside of the 16 bytes at 0xC010 - 0xC01F has no affect on the picture, and whatever is written in that range is repeated on the screen

Going to take a break for a while to think about this, but my current thought is that maybe those 16 bytes are being read repeatedly by the output circuit, possibly by a short I have yet to find.

eduardocasino, 2024-02-11:
Mmmmm... Is it just the display? I mean, does the RAM works correctly as storage?

ryaneroth, 2024-02-11:
Yep, I meant to include that in my last post, the ram passes testing, and stores data correctly

eduardocasino, 2024-02-11:
Okay, that narrows down the problem quite a bit. I'll check the schematic to see if I can give you any hints.

ryaneroth, 2024-02-11:
Actually this is no longer true, I pulled all the RAM when checking the bus for shorts, and after putting it back in, it does not all work, and has picked up an odd behavior.  Any address over C3FF now returns the first two bits of the address as what is in memory and I cannot change the value 😞

eduardocasino, 2024-02-11:
If the RAM worked correctly, and I assume you got it working at some point, then I think the problem must be in the counter that generates the addresses for refreshing the ram chips and, more specifically, to U19. The symptoms you describe are explained if U19A is stuck  at Q0 == 1 and only U19B is counting correctly:

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

Check around U19 for shorts and/or replace it.

ryaneroth, 2024-02-11:
Thanks. I'll dig into this!

eduardocasino, 2024-02-11:
Just to clarify, the above is correct if the RAM is working OK and the display only displays contents from 0xC010 - 0xC01F over and over. First thing to do is to get the RAM working again.

ryaneroth, 2024-02-11:
Wow, this is super embarrassing seeing how many hours I spent examining this card.  Pin 9 on U34 was bent outside its socket 😭 🤦

Thank you again for all your help!

Here is our reward:
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

eduardocasino, 2024-02-11:
Glad you got it working!

I assume the color artifacts are caused by the camera, aren't they?

ryaneroth, 2024-02-11:
I'm using a USB capture card, and it introduces the color artifacts when it can't hold a good sync

My quick version
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
of this
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

eduardocasino, 2024-02-11:
Ah, yes, happened to me too with a video to hdmi converter:

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

ryaneroth, 2024-02-11:
It works pretty well for costing $25, but I realize a CRT would work better. On Feb 11, 2024, at 3:56 PM, Eduardo Casino ***@***.***> wrote:
Ah, yes, happened to me too with a video to hdmi converter:
bender_artifacts.png (view on web)

—Reply to this email directly, view it on GitHub, or unsubscribe.You are receiving this because you were mentioned.Message ID: ***@***.***>

Closed 2024-02-12.

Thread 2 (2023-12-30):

Data bus transceiver must be put in high impedance state when DECEN is low

eduardocasino, 2023-12-30:
The 74LS245 data bus transceiver (U4 in the schematic) is enabled permanently (the OE line is tied to ground) This means that when the KIM-1 is handling the address decoding and the ~R/W line is  low, both the KIM-1 and the transceiver are trying to drive the data bus, which renders the system unusable.

The solution is to disable the transceiver when DECEN is low, so the OE line must be driven by DECEN through an inverter.

Until this is fixed, the board is useless.

eduardocasino, 2023-12-31:
The transceiver must be disabled also when K7 is low (interrupt vectors pointing to the kim-1 system ROM)

ryaneroth, 2023-12-31:
I soldered up one of the expansion bus slots, and threw the RAM board on it, and it is working.  RAM test passed.

Closed 2024-02-17.

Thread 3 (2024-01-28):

Aux cards not working with Corsham's SD Shield

eduardocasino, 2024-01-28:
Both versions (RS-232 and USB) are affected. The PA6 and PA7 lines are connected to 3K3 pull-up resistors (for the IEC interface to work) causing that bits 6 and 7 of the PA bus are never set on a write operation. The boards need jumpers or switches to select which interface (IEC or SD Shield) to use.

EDIT: Nothing to do with the pull-ups, but to the fact that PA6 and PA7 are connected to inverted PA4 and PA5 so, anytime any of the later are high, force the former to be low. So, right solution (jumpers), but wrong diagnosis.

Closed 2024-02-17.

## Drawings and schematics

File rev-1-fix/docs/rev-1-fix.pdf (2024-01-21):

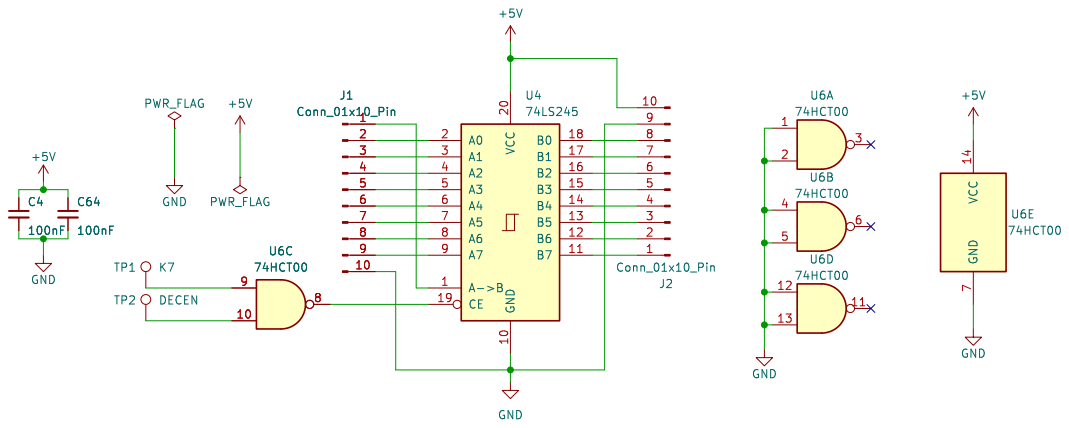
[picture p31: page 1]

Id: 1/1 Title: File: rev-1-fix.kicad_sch Sheet: /

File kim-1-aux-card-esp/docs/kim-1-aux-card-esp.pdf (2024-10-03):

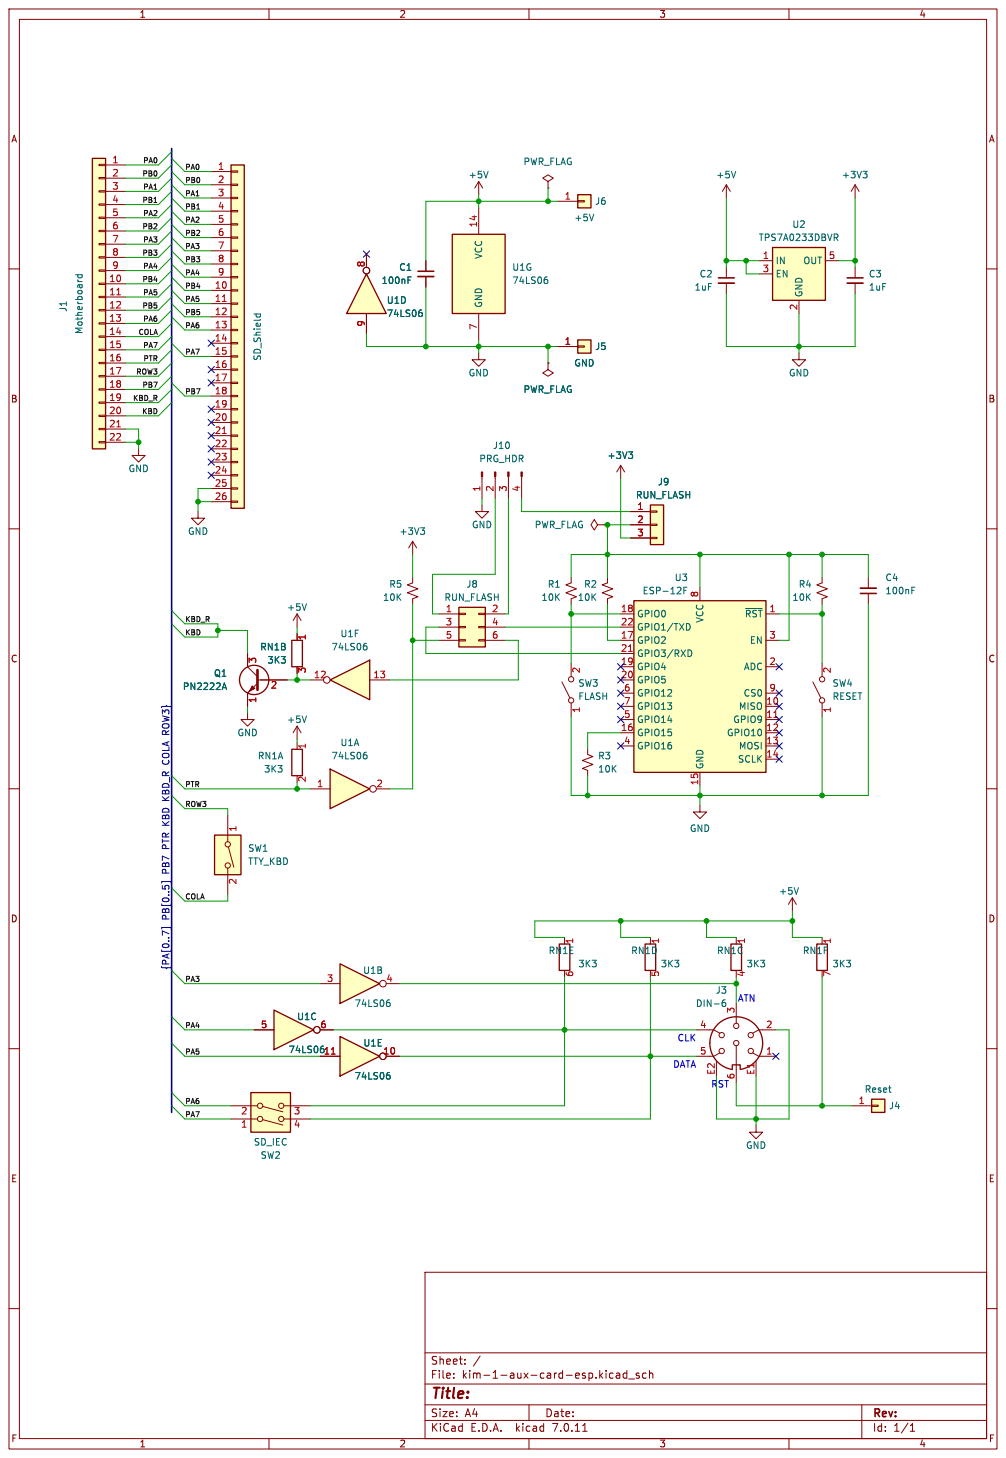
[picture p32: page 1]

2 EN 3 OUT 5 U2 TPS7A0233DBVR VCC 14 GND

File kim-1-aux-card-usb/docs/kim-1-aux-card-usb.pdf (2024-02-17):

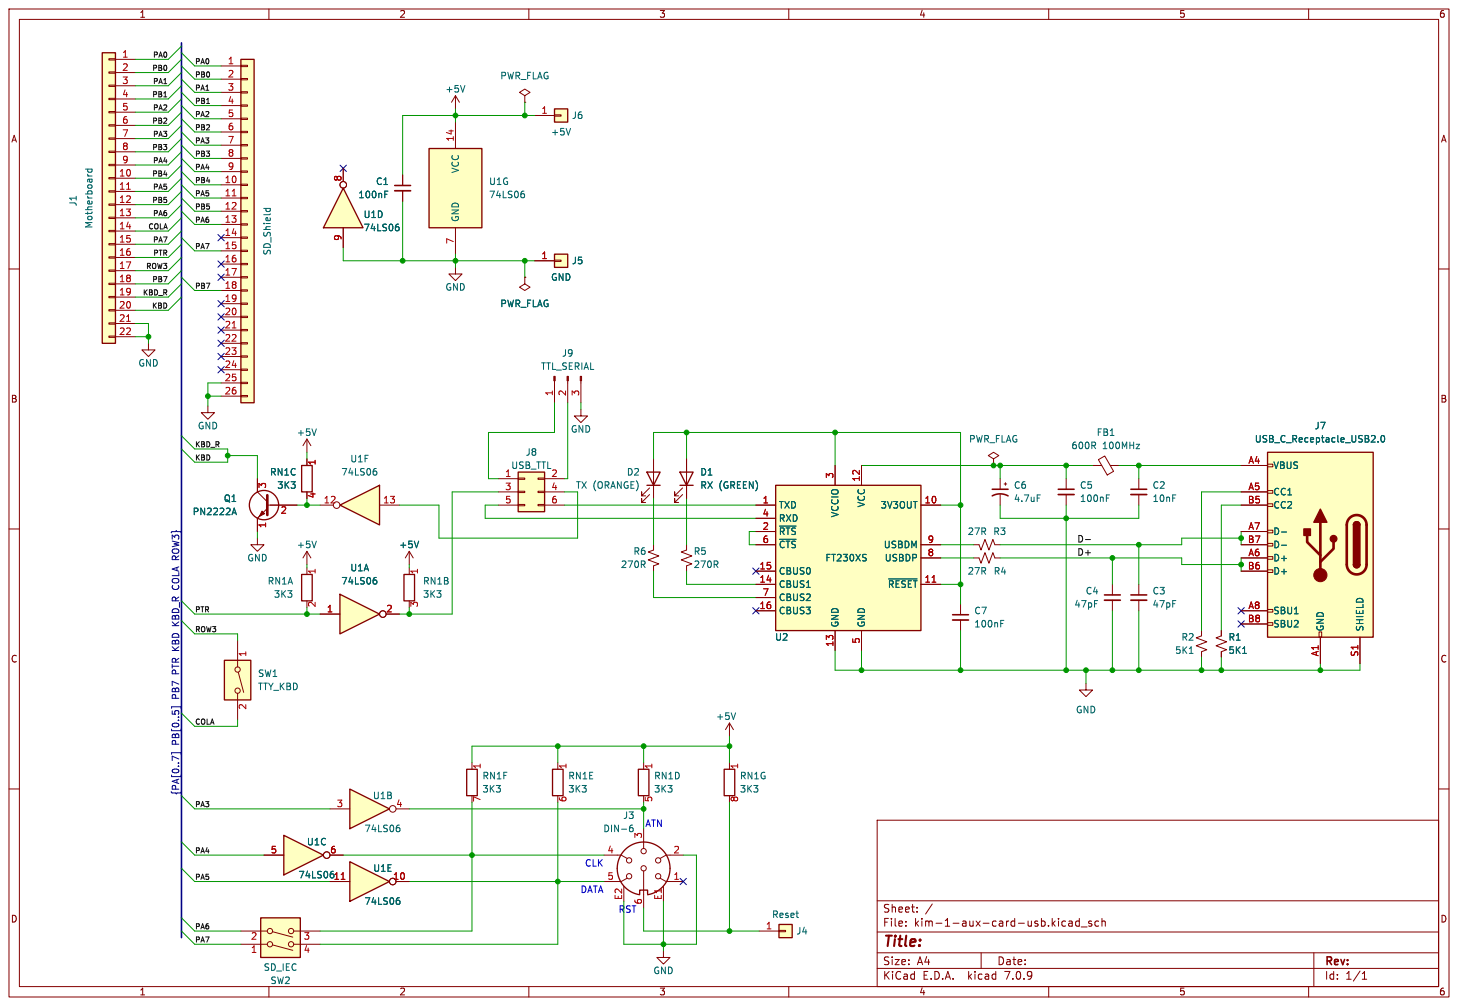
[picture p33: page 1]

Id: 1/1 Title: File: kim-1-aux-card-usb.kicad_sch Sheet: / 1 5 RN1D

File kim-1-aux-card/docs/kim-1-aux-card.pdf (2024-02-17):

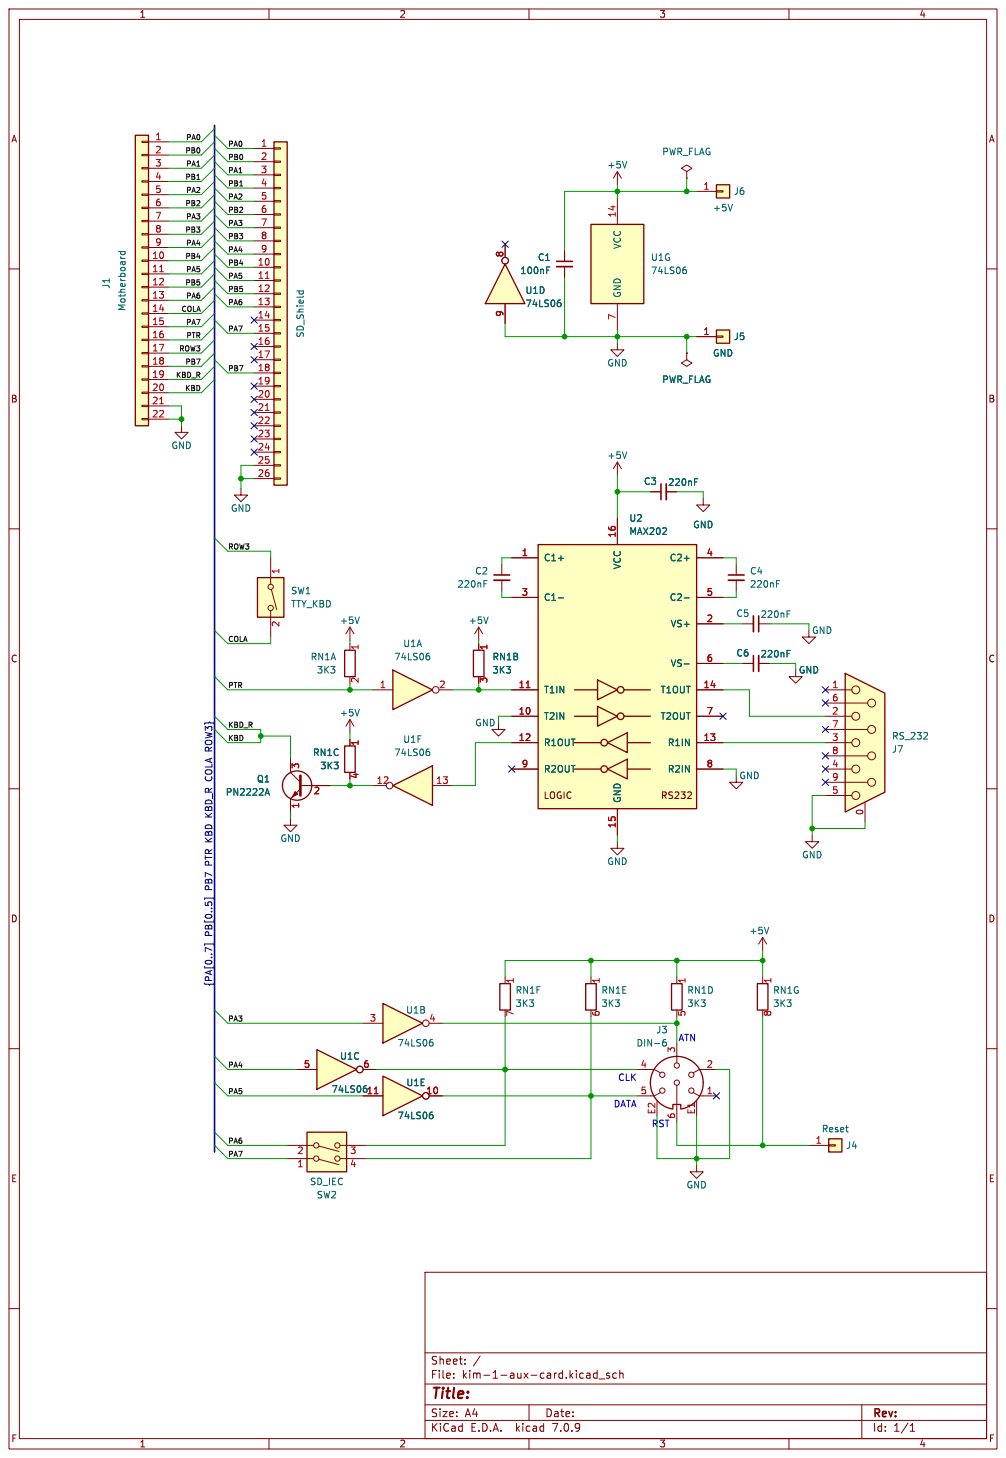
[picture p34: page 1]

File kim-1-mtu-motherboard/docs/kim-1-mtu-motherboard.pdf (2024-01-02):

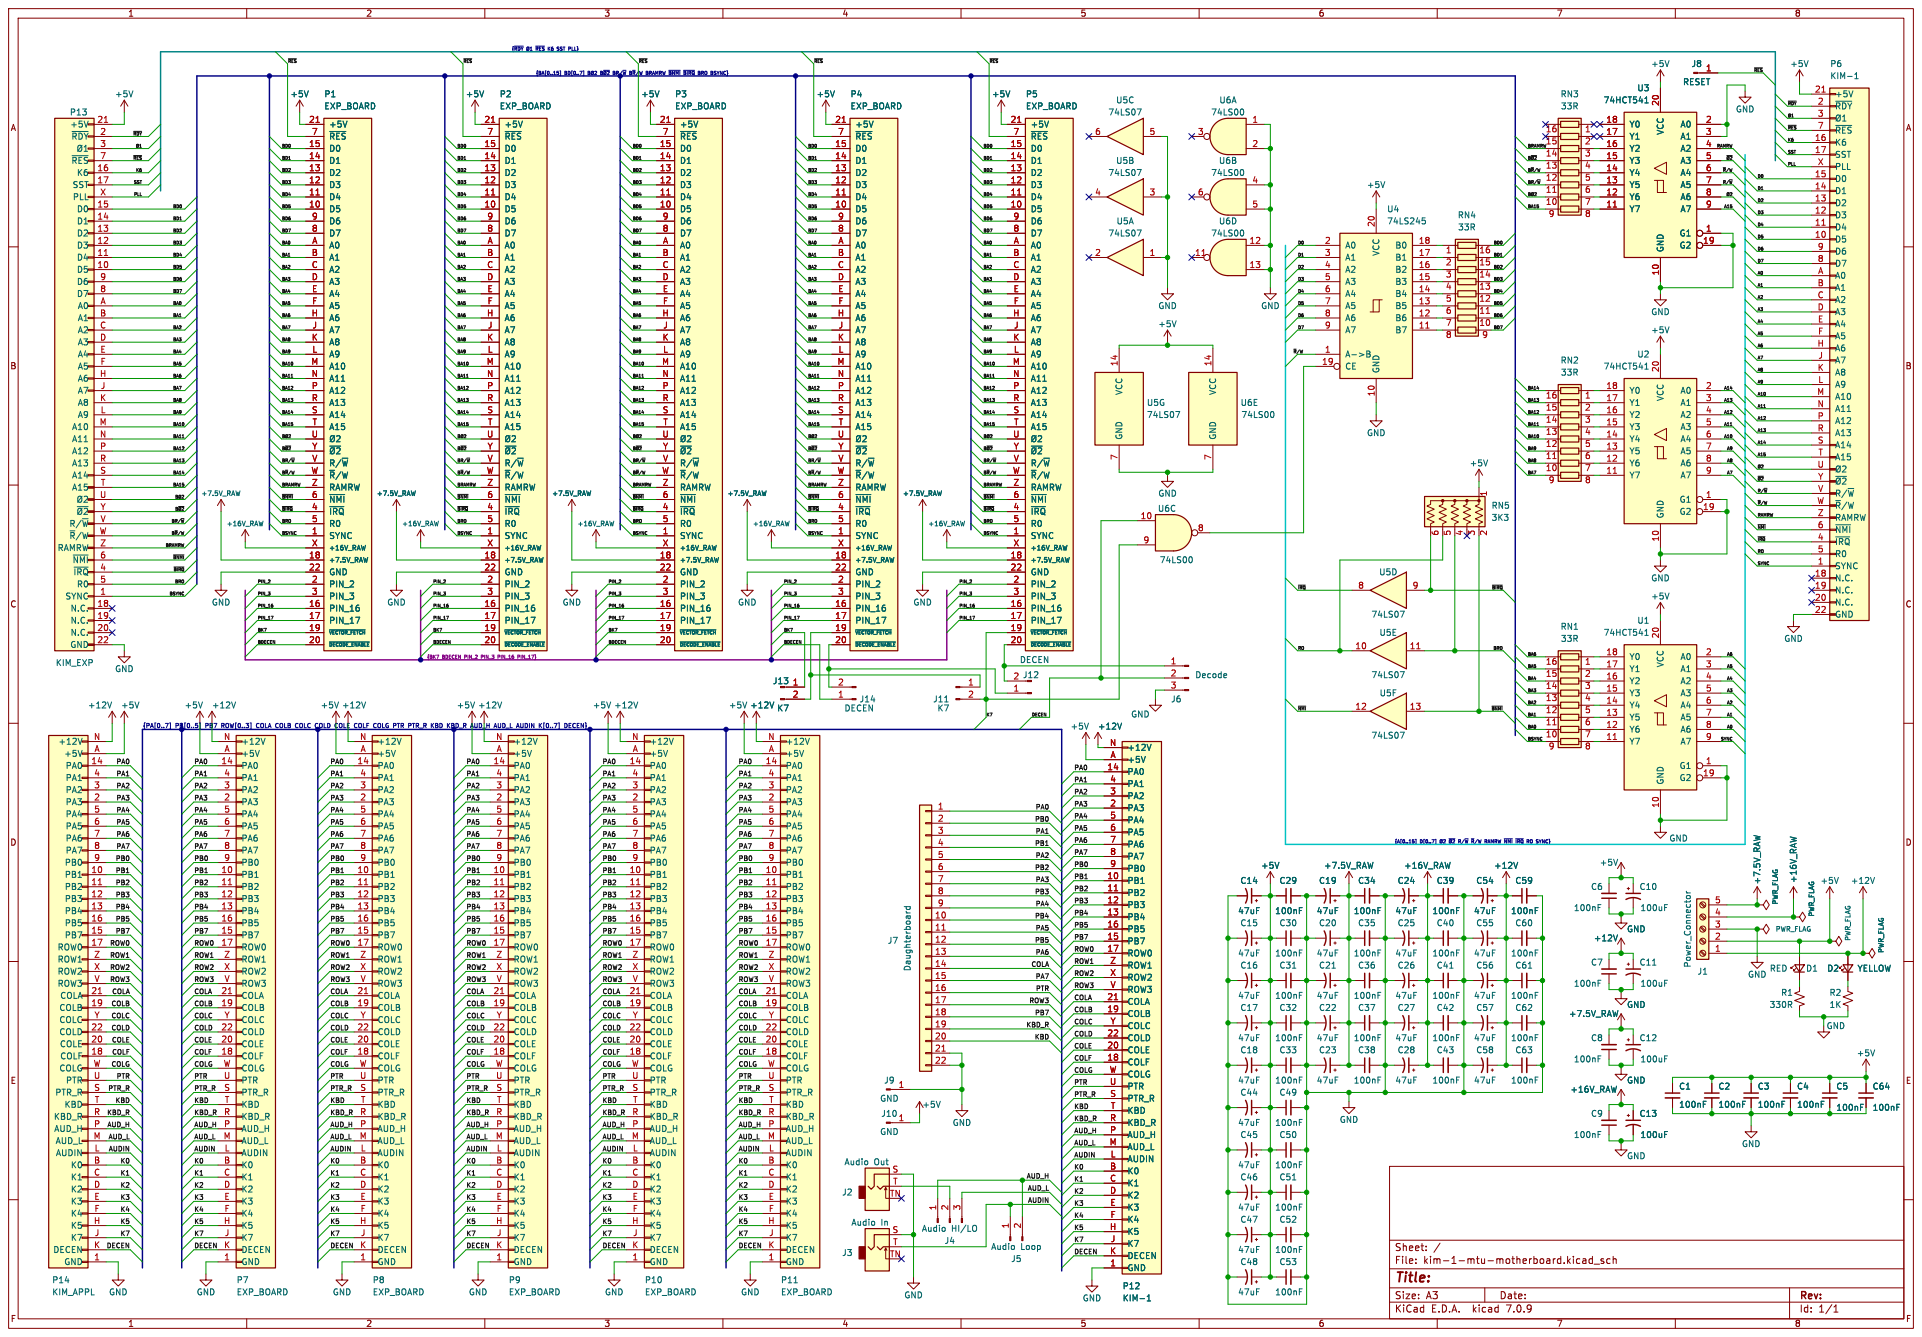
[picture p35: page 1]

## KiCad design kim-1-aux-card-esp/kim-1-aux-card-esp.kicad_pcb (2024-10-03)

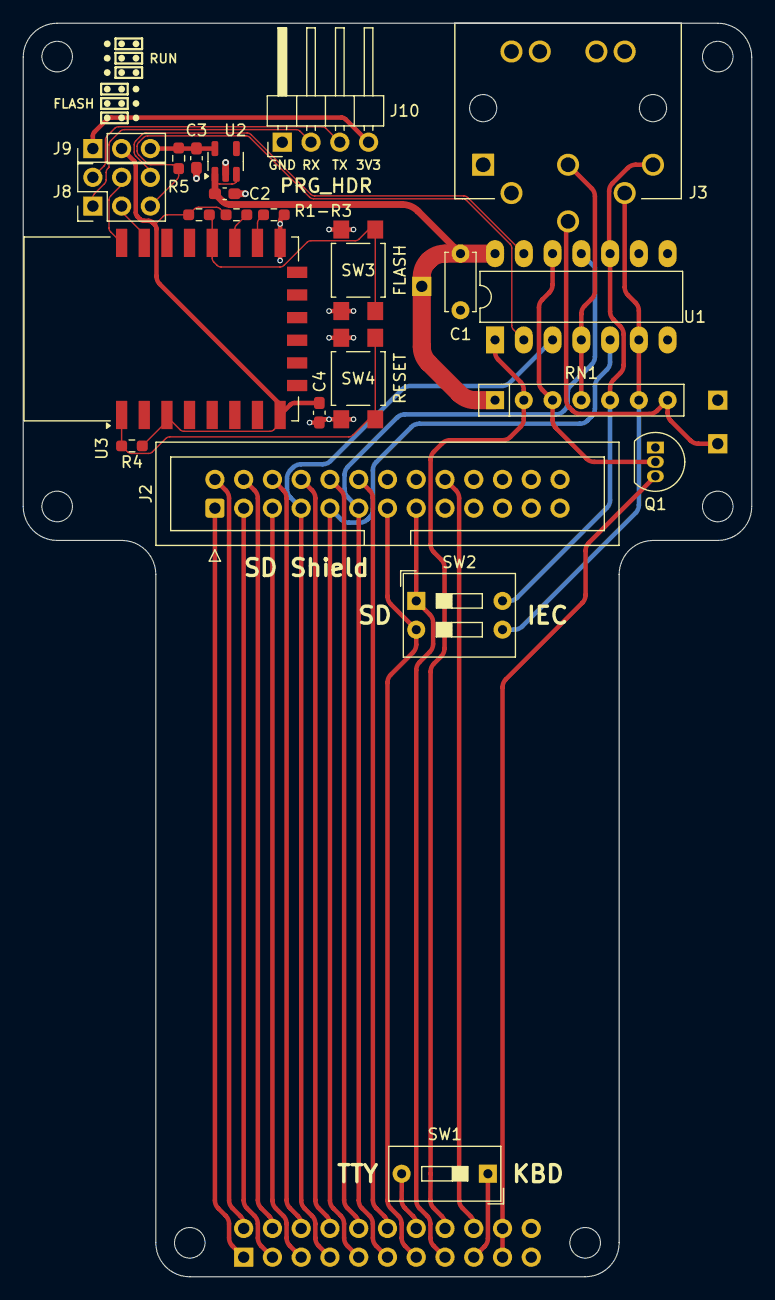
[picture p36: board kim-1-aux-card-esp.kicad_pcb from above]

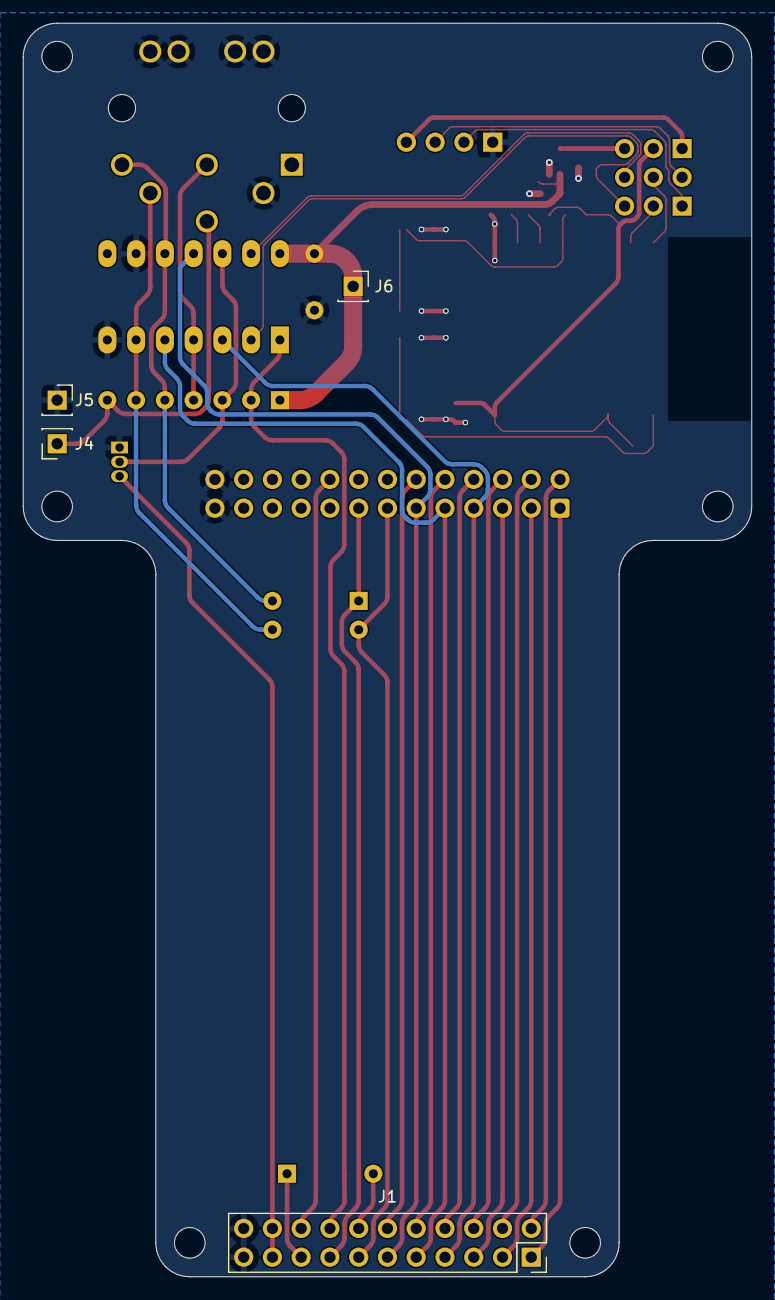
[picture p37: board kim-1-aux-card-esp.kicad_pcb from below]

Board: 2 copper layers, 64.3 x 110.7 mm, 27 parts (4 on the bottom side), 39 nets.

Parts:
C1: 100nF; C_Disc_D5.0mm_W2.5mm_P5.00mm
C2, C3: 1uF; C_0603_1608Metric_Pad1.08x0.95mm_HandSolder
C4: 100nF; C_0603_1608Metric_Pad1.08x0.95mm_HandSolder
J1: Motherboard; PinSocket_2x11_P2.54mm_Vertical
J2: SD_Shield; IDC-Header_2x13_P2.54mm_Vertical
J3: DIN-6; CUI_SDS-60J
J4: Reset; PinSocket_1x01_P2.54mm_Vertical
J5: GND; PinSocket_1x01_P2.54mm_Vertical
J6: +5V; PinSocket_1x01_P2.54mm_Vertical
J8: RUN_FLASH; PinHeader_2x03_P2.54mm_Vertical
J9: RUN_FLASH; PinHeader_1x03_P2.54mm_Vertical
J10: PRG_HDR; PinHeader_1x04_P2.54mm_Horizontal
Q1: PN2222A; TO-92_Inline
R1, R2, R3, R4, R5: 10K; R_0603_1608Metric_Pad0.98x0.95mm_HandSolder
RN1: 3K3; R_Array_SIP7
SW1: TTY_KBD; SW_DIP_SPSTx01_Slide_9.78x4.72mm_W7.62mm_P2.54mm
SW2: SD_IEC; SW_DIP_SPSTx02_Slide_9.78x7.26mm_W7.62mm_P2.54mm
SW3: FLASH; SW_SPST_TL3305A
SW4: RESET; SW_SPST_TL3305A
U1: 74LS06; DIP-14_W7.62mm_LongPads
U2: TPS7A0233DBVR; SOT-23-5
U3: ESP-12F; ESP-12E

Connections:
+3V3: C3.1, J9.3, R5.1, U2.5 (OUT)
+5V: C1.1, C2.1, J6.1, RN1.1 (R1), U1.14 (VCC), U2.1 (IN), U2.3 (EN)
/COLA: J1.14, SW1.2
/KBD: J1.19, J1.20, Q1.3 (C)
/PA0: J1.1, J2.1
/PA1: J1.3, J2.3
/PA2: J1.5, J2.5
/PA3: J1.7, J2.7, U1.3
/PA4: J1.9, J2.9, U1.5
/PA5: J1.11, J2.11, U1.11
/PA6: J1.13, J2.13, SW2.2
/PA7: J1.15, J2.15, SW2.1
/PB0: J1.2, J2.2
/PB1: J1.4, J2.4
/PB2: J1.6, J2.6
/PB3: J1.8, J2.8
/PB4: J1.10, J2.10
/PB5: J1.12, J2.12
/PB7: J1.18, J2.18
/PTR: J1.16, RN1.2 (R1.2), U1.1
/ROW3: J1.17, SW1.1
GND: C1.2, C2.2, C3.2, C4.1, J1.21, J1.22, J2.25, J2.26, J3.2, J3.E1, J3.E2, J5.1, J10.1, Q1.1 (E), R3.2, SW3.1 (A), SW4.1 (A), U1.7 (GND), U1.9, U2.2 (GND), U3.15 (GND)
unnamed: J3.6, J4.1, RN1.7 (R6.2)
unnamed: J8.3, U3.21 (GPIO3/RXD)
unnamed: J8.4, U3.22 (GPIO1/TXD)
unnamed: J8.5, R5.2, U1.2
unnamed: J8.6, U1.13
unnamed: C4.2, J9.2, R1.1, R2.1, R4.1, U3.3 (EN), U3.8 (VCC)
unnamed: J8.1, J10.2
unnamed: J8.2, J10.3
unnamed: J9.1, J10.4
unnamed: Q1.2 (B), RN1.3 (R2.2), U1.12
unnamed: J3.3, RN1.4 (R3.2), U1.4
unnamed: J3.5, RN1.5 (R4.2), SW2.4, U1.10
unnamed: J3.4, RN1.6 (R5.2), SW2.3, U1.6
unnamed: R1.2, SW3.2 (B), U3.18 (GPIO0)
unnamed: R4.2, SW4.2 (B), U3.1 (~RST)
unnamed: R2.2, U3.17 (GPIO2)
unnamed: R3.1, U3.16 (GPIO15)

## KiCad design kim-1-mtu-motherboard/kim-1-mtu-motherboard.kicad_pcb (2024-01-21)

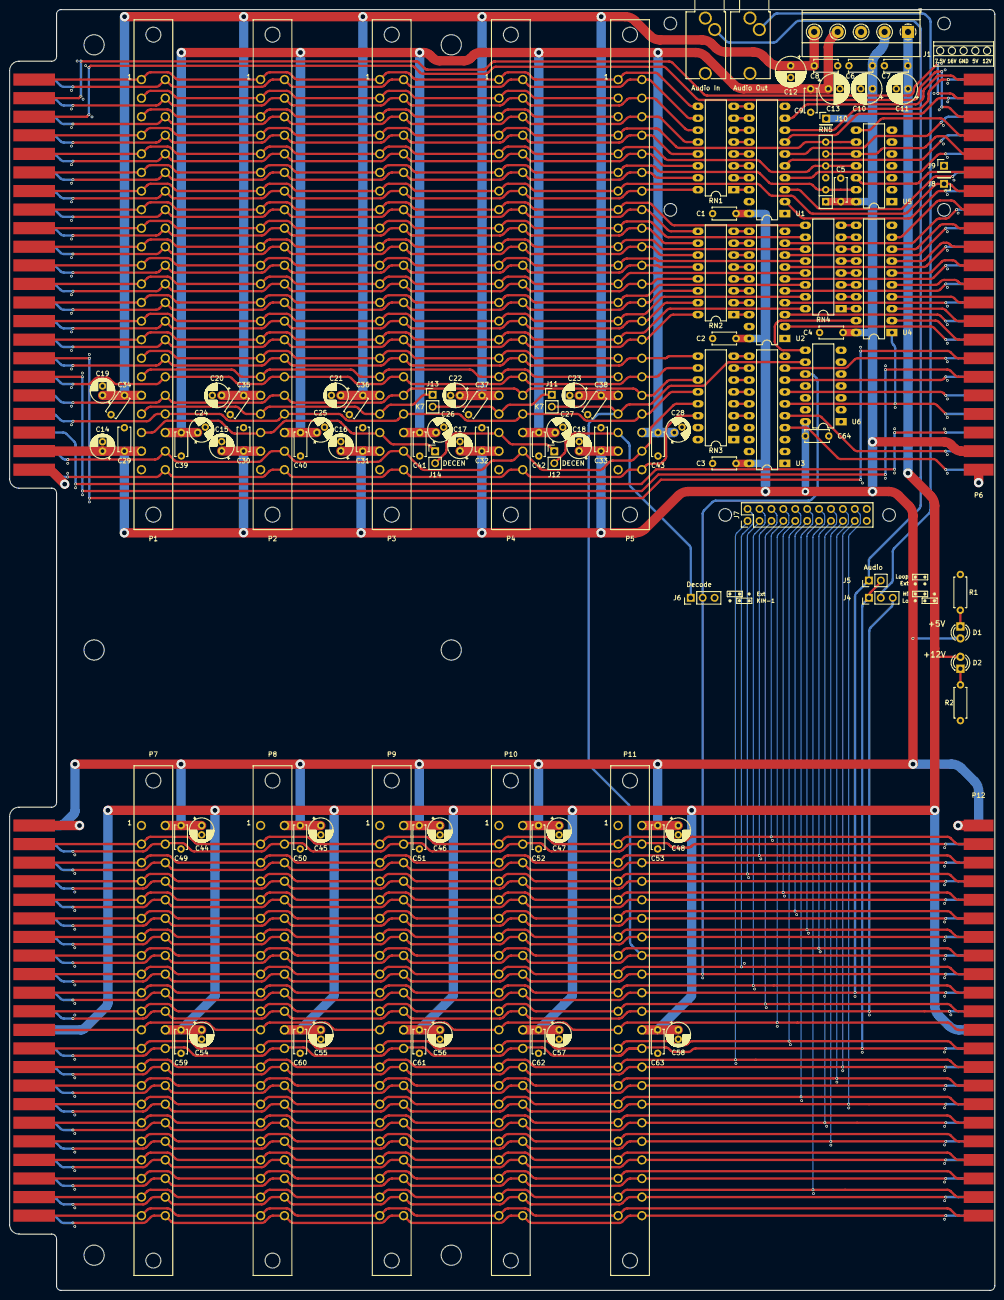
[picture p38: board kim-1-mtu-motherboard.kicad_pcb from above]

Board: 2 copper layers, 210.0 x 273.0 mm, 107 parts (0 on the bottom side), 161 nets.

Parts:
C1, C2, C3, C4, C5, C6, C7, C8, C9, C29, C30, C31, C32, C33, C34, C35, C36, C37, C38, C39, C40, C41, C42, C43, C49, C50, C51, C52, C53, C59, C60, C61, C62, C63, C64: 100nF; C_Disc_D5.0mm_W2.5mm_P5.00mm
C10, C11, C12, C13: 100uF; CP_Radial_D6.3mm_P2.50mm
C14, C15, C16, C17, C18, C19, C20, C21, C22, C23, C24, C25, C26, C27, C28, C44, C45, C46, C47, C48, C54, C55, C56, C57, C58: 47uF; CP_Radial_D5.0mm_P2.00mm
D1: RED; LED_D3.0mm
D2: YELLOW; LED_D3.0mm
J1: Power_Connector; TerminalBlock_Phoenix_MKDS-1,5-5_1x05_P5.00mm_Horizontal
J2: Audio Out; Jack_3.5mm_35RAPC2AVN4_Horizontal_CircularHoles
J3: Audio In; Jack_3.5mm_35RAPC2AVN4_Horizontal_CircularHoles
J4: Audio HI/LO; PinHeader_1x03_P2.54mm_Vertical
J5: Audio Loop; PinHeader_1x02_P2.54mm_Vertical
J6: Decode; PinHeader_1x03_P2.54mm_Vertical
J7: Daughterboard; PinHeader_2x11_P2.54mm_Vertical
J8: RESET; PinHeader_1x01_P2.54mm_Vertical
J9, J10: GND; PinHeader_1x01_P2.54mm_Vertical
J11, J13: K7; PinHeader_1x02_P2.54mm_Vertical
J12, J14: DECEN; PinHeader_1x02_P2.54mm_Vertical
P1, P2, P3, P4, P5, P7, P8, P9, P10, P11: EXP_BOARD; EDAC-3.96-2x22
P6, P12: KIM-1; KIM_EDGE
P13: KIM_EXP; KIM_CONN
P14: KIM_APPL; KIM_CONN
R1: 330R; R_Axial_DIN0207_L6.3mm_D2.5mm_P7.62mm_Horizontal
R2: 1K; R_Axial_DIN0207_L6.3mm_D2.5mm_P7.62mm_Horizontal
RN1, RN2, RN3, RN4: 33R; DIP-16_W7.62mm_LongPads
RN5: 3K3; R_Array_SIP6
U1, U2, U3: 74HCT541; DIP-20_W7.62mm_LongPads
U4: 74LS245; DIP-20_W7.62mm_LongPads
U5: 74LS07; DIP-14_W7.62mm_LongPads
U6: 74LS00; DIP-14_W7.62mm_LongPads

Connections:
+5V: C1.1, C2.1, C3.1, C4.1, C5.1, C6.2, C10.1, C14.1, C15.1, C16.1, C17.1, C18.1, C29.1, C30.1, C31.1, C32.1, C33.1, C44.1, C45.1, C46.1, C47.1, C48.1, C49.1, C50.1, C51.1, C52.1, C53.1, C64.1, D1.2 (A), J1.2, J10.1, P1.21 (+5V), P2.21 (+5V), P3.21 (+5V), P4.21 (+5V), P5.21 (+5V), P6.21 (+5V), P7.A (+5V), P8.A (+5V), P9.A (+5V), P10.A (+5V), P11.A (+5V), P12.A (+5V), P13.21 (+5V), P14.A (+5V), RN5.1 (common), U1.20 (VCC), U2.20 (VCC), U3.20 (VCC), U4.20 (VCC), U5.14 (VCC), U6.14 (VCC)
+7.5V_RAW: C8.2, C12.1, C19.1, C20.1, C21.1, C22.1, C23.1, C34.1, C35.1, C36.1, C37.1, C38.1, J1.5, P1.18 (+7.5V_RAW), P2.18 (+7.5V_RAW), P3.18 (+7.5V_RAW), P4.18 (+7.5V_RAW), P5.18 (+7.5V_RAW)
+12V: C7.2, C11.1, C54.1, C55.1, C56.1, C57.1, C58.1, C59.1, C60.1, C61.1, C62.1, C63.1, D2.2 (A), J1.1, P7.N (+12V), P8.N (+12V), P9.N (+12V), P10.N (+12V), P11.N (+12V), P12.N (+12V), P14.N (+12V)
+16V_RAW: C9.2, C13.1, C24.1, C25.1, C26.1, C27.1, C28.1, C39.1, C40.1, C41.1, C42.1, C43.1, J1.4, P1.X (+16V_RAW), P2.X (+16V_RAW), P3.X (+16V_RAW), P4.X (+16V_RAW), P5.X (+16V_RAW)
/A0: P6.A (A0), U1.8 (A6)
/A1: P6.B (A1), U1.7 (A5)
/A2: P6.C (A2), U1.6 (A4)
/A3: P6.D (A3), U1.5 (A3)
/A4: P6.E (A4), U1.4 (A2)
/A5: P6.F (A5), U1.3 (A1)
/A6: P6.H (A6), U1.2 (A0)
/A7: P6.J (A7), U2.9 (A7)
/A8: P6.K (A8), U2.8 (A6)
/A9: P6.L (A9), U2.7 (A5)
/A10: P6.M (A10), U2.6 (A4)
/A11: P6.N (A11), U2.5 (A3)
/A12: P6.P (A12), U2.4 (A2)
/A13: P6.R (A13), U2.3 (A1)
/A14: P6.S (A14), U2.2 (A0)
/A15: P6.T (A15), U3.9 (A7)
/AUDIN: J3.T, J5.1, P7.L (AUDIN), P8.L (AUDIN), P9.L (AUDIN), P10.L (AUDIN), P11.L (AUDIN), P12.L (AUDIN), P14.L (AUDIN)
/AUD_H: J4.1, J5.2, P7.P (AUD_H), P8.P (AUD_H), P9.P (AUD_H), P10.P (AUD_H), P11.P (AUD_H), P12.P (AUD_H), P14.P (AUD_H)
/AUD_L: J4.3, P7.M (AUD_L), P8.M (AUD_L), P9.M (AUD_L), P10.M (AUD_L), P11.M (AUD_L), P12.M (AUD_L), P14.M (AUD_L)
/BA0: P1.A (A0), P2.A (A0), P3.A (A0), P4.A (A0), P5.A (A0), P13.A (A0), RN1.10 (R7.2)
/BA1: P1.B (A1), P2.B (A1), P3.B (A1), P4.B (A1), P5.B (A1), P13.B (A1), RN1.11 (R6.2)
/BA2: P1.C (A2), P2.C (A2), P3.C (A2), P4.C (A2), P5.C (A2), P13.C (A2), RN1.12 (R5.2)
/BA3: P1.D (A3), P2.D (A3), P3.D (A3), P4.D (A3), P5.D (A3), P13.D (A3), RN1.13 (R4.2)
/BA4: P1.E (A4), P2.E (A4), P3.E (A4), P4.E (A4), P5.E (A4), P13.E (A4), RN1.14 (R3.2)
/BA5: P1.F (A5), P2.F (A5), P3.F (A5), P4.F (A5), P5.F (A5), P13.F (A5), RN1.15 (R2.2)
/BA6: P1.H (A6), P2.H (A6), P3.H (A6), P4.H (A6), P5.H (A6), P13.H (A6), RN1.16 (R1.2)
/BA7: P1.J (A7), P2.J (A7), P3.J (A7), P4.J (A7), P5.J (A7), P13.J (A7), RN2.9 (R8.2)
/BA8: P1.K (A8), P2.K (A8), P3.K (A8), P4.K (A8), P5.K (A8), P13.K (A8), RN2.10 (R7.2)
/BA9: P1.L (A9), P2.L (A9), P3.L (A9), P4.L (A9), P5.L (A9), P13.L (A9), RN2.11 (R6.2)
/BA10: P1.M (A10), P2.M (A10), P3.M (A10), P4.M (A10), P5.M (A10), P13.M (A10), RN2.12 (R5.2)
/BA11: P1.N (A11), P2.N (A11), P3.N (A11), P4.N (A11), P5.N (A11), P13.N (A11), RN2.13 (R4.2)
/BA12: P1.P (A12), P2.P (A12), P3.P (A12), P4.P (A12), P5.P (A12), P13.P (A12), RN2.14 (R3.2)
/BA13: P1.R (A13), P2.R (A13), P3.R (A13), P4.R (A13), P5.R (A13), P13.R (A13), RN2.15 (R2.2)
/BA14: P1.S (A14), P2.S (A14), P3.S (A14), P4.S (A14), P5.S (A14), P13.S (A14), RN2.16 (R1.2)
/BA15: P1.T (A15), P2.T (A15), P3.T (A15), P4.T (A15), P5.T (A15), P13.T (A15), RN3.9 (R8.2)
/BD0: P1.15 (D0), P2.15 (D0), P3.15 (D0), P4.15 (D0), P5.15 (D0), P13.15 (D0), RN4.16 (R1.2)
/BD1: P1.14 (D1), P2.14 (D1), P3.14 (D1), P4.14 (D1), P5.14 (D1), P13.14 (D1), RN4.15 (R2.2)
/BD2: P1.13 (D2), P2.13 (D2), P3.13 (D2), P4.13 (D2), P5.13 (D2), P13.13 (D2), RN4.14 (R3.2)
/BD3: P1.12 (D3), P2.12 (D3), P3.12 (D3), P4.12 (D3), P5.12 (D3), P13.12 (D3), RN4.13 (R4.2)
/BD4: P1.11 (D4), P2.11 (D4), P3.11 (D4), P4.11 (D4), P5.11 (D4), P13.11 (D4), RN4.12 (R5.2)
/BD5: P1.10 (D5), P2.10 (D5), P3.10 (D5), P4.10 (D5), P5.10 (D5), P13.10 (D5), RN4.11 (R6.2)
/BD6: P1.9 (D6), P2.9 (D6), P3.9 (D6), P4.9 (D6), P5.9 (D6), P13.9 (D6), RN4.10 (R7.2)
/BD7: P1.8 (D7), P2.8 (D7), P3.8 (D7), P4.8 (D7), P5.8 (D7), P13.8 (D7), RN4.9 (R8.2)
/BDECEN: J14.1, P1.20 (~DECODE_ENABLE), P2.20 (~DECODE_ENABLE), P3.20 (~DECODE_ENABLE)
/BK7: J13.1, P1.19 (~VECTOR_FETCH), P2.19 (~VECTOR_FETCH), P3.19 (~VECTOR_FETCH)
/BRAMRW: P1.Z (RAMRW), P2.Z (RAMRW), P3.Z (RAMRW), P4.Z (RAMRW), P5.Z (RAMRW), P13.Z (RAMRW), RN3.14 (R3.2)
/BRO: P1.5 (R0), P2.5 (R0), P3.5 (R0), P4.5 (R0), P5.5 (R0), P13.5 (R0), RN5.4 (R3), U5.11
/BR/~W: P1.V (R/~W), P2.V (R/~W), P3.V (R/~W), P4.V (R/~W), P5.V (R/~W), P13.V (R/~W), RN3.11 (R6.2)
/BSYNC: P1.1 (SYNC), P2.1 (SYNC), P3.1 (SYNC), P4.1 (SYNC), P5.1 (SYNC), P13.1 (SYNC), RN1.9 (R8.2)
/B~R/W: P1.W (~R/W), P2.W (~R/W), P3.W (~R/W), P4.W (~R/W), P5.W (~R/W), P13.W (~R/W), RN3.12 (R5.2)
/B~Ø2: P1.Y (~Ø2), P2.Y (~Ø2), P3.Y (~Ø2), P4.Y (~Ø2), P5.Y (~Ø2), P13.Y (~Ø2), RN3.13 (R4.2)
/BØ2: P1.U (Ø2), P2.U (Ø2), P3.U (Ø2), P4.U (Ø2), P5.U (Ø2), P13.U (Ø2), RN3.10 (R7.2)
/COLA: J7.14, P7.21 (COLA), P8.21 (COLA), P9.21 (COLA), P10.21 (COLA), P11.21 (COLA), P12.21 (COLA), P14.21 (COLA)
/COLB: P7.19 (COLB), P8.19 (COLB), P9.19 (COLB), P10.19 (COLB), P11.19 (COLB), P12.19 (COLB), P14.19 (COLB)
/COLC: P7.Y (COLC), P8.Y (COLC), P9.Y (COLC), P10.Y (COLC), P11.Y (COLC), P12.Y (COLC), P14.Y (COLC)
/COLD: P7.22 (COLD), P8.22 (COLD), P9.22 (COLD), P10.22 (COLD), P11.22 (COLD), P12.22 (COLD), P14.22 (COLD)
/COLE: P7.20 (COLE), P8.20 (COLE), P9.20 (COLE), P10.20 (COLE), P11.20 (COLE), P12.20 (COLE), P14.20 (COLE)
/COLF: P7.18 (COLF), P8.18 (COLF), P9.18 (COLF), P10.18 (COLF), P11.18 (COLF), P12.18 (COLF), P14.18 (COLF)
/COLG: P7.W (COLG), P8.W (COLG), P9.W (COLG), P10.W (COLG), P11.W (COLG), P12.W (COLG), P14.W (COLG)
/D0: P6.15 (D0), U4.2 (A0)
/D1: P6.14 (D1), U4.3 (A1)
/D2: P6.13 (D2), U4.4 (A2)
/D3: P6.12 (D3), U4.5 (A3)
/D4: P6.11 (D4), U4.6 (A4)
/D5: P6.10 (D5), U4.7 (A5)
/D6: P6.9 (D6), U4.8 (A6)
/D7: P6.8 (D7), U4.9 (A7)
/DECEN: J6.2, P7.K (DECEN), P8.K (DECEN), P9.K (DECEN), P10.K (DECEN), P11.K (DECEN), P12.K (DECEN), P14.K (DECEN), U6.10
/K0: P7.B (K0), P8.B (K0), P9.B (K0), P10.B (K0), P11.B (K0), P12.B (K0), P14.B (K0)
/K1: P7.C (K1), P8.C (K1), P9.C (K1), P10.C (K1), P11.C (K1), P12.C (K1), P14.C (K1)
/K2: P7.D (K2), P8.D (K2), P9.D (K2), P10.D (K2), P11.D (K2), P12.D (K2), P14.D (K2)
/K3: P7.E (K3), P8.E (K3), P9.E (K3), P10.E (K3), P11.E (K3), P12.E (K3), P14.E (K3)
/K4: P7.F (K4), P8.F (K4), P9.F (K4), P10.F (K4), P11.F (K4), P12.F (K4), P14.F (K4)
/K5: P7.H (K5), P8.H (K5), P9.H (K5), P10.H (K5), P11.H (K5), P12.H (K5), P14.H (K5)
/K6: P6.16 (K6), P13.16 (K6)
/K7: J11.2, P5.19 (~VECTOR_FETCH), P7.J (K7), P8.J (K7), P9.J (K7), P10.J (K7), P11.J (K7), P12.J (K7), P14.J (K7), U6.9
/KBD: J7.20, P7.T (KBD), P8.T (KBD), P9.T (KBD), P10.T (KBD), P11.T (KBD), P12.T (KBD), P14.T (KBD)
/KBD_R: J7.19, P7.R (KBD_R), P8.R (KBD_R), P9.R (KBD_R), P10.R (KBD_R), P11.R (KBD_R), P12.R (KBD_R), P14.R (KBD_R)
/PA0: J7.1, P7.14 (PA0), P8.14 (PA0), P9.14 (PA0), P10.14 (PA0), P11.14 (PA0), P12.14 (PA0), P14.14 (PA0)
/PA1: J7.3, P7.4 (PA1), P8.4 (PA1), P9.4 (PA1), P10.4 (PA1), P11.4 (PA1), P12.4 (PA1), P14.4 (PA1)
/PA2: J7.5, P7.3 (PA2), P8.3 (PA2), P9.3 (PA2), P10.3 (PA2), P11.3 (PA2), P12.3 (PA2), P14.3 (PA2)
/PA3: J7.7, P7.2 (PA3), P8.2 (PA3), P9.2 (PA3), P10.2 (PA3), P11.2 (PA3), P12.2 (PA3), P14.2 (PA3)
/PA4: J7.9, P7.5 (PA4), P8.5 (PA4), P9.5 (PA4), P10.5 (PA4), P11.5 (PA4), P12.5 (PA4), P14.5 (PA4)
/PA5: J7.11, P7.6 (PA5), P8.6 (PA5), P9.6 (PA5), P10.6 (PA5), P11.6 (PA5), P12.6 (PA5), P14.6 (PA5)
/PA6: J7.13, P7.7 (PA6), P8.7 (PA6), P9.7 (PA6), P10.7 (PA6), P11.7 (PA6), P12.7 (PA6), P14.7 (PA6)
/PA7: J7.15, P7.8 (PA7), P8.8 (PA7), P9.8 (PA7), P10.8 (PA7), P11.8 (PA7), P12.8 (PA7), P14.8 (PA7)
/PB0: J7.2, P7.9 (PB0), P8.9 (PB0), P9.9 (PB0), P10.9 (PB0), P11.9 (PB0), P12.9 (PB0), P14.9 (PB0)
/PB1: J7.4, P7.10 (PB1), P8.10 (PB1), P9.10 (PB1), P10.10 (PB1), P11.10 (PB1), P12.10 (PB1), P14.10 (PB1)
/PB2: J7.6, P7.11 (PB2), P8.11 (PB2), P9.11 (PB2), P10.11 (PB2), P11.11 (PB2), P12.11 (PB2), P14.11 (PB2)
/PB3: J7.8, P7.12 (PB3), P8.12 (PB3), P9.12 (PB3), P10.12 (PB3), P11.12 (PB3), P12.12 (PB3), P14.12 (PB3)
/PB4: J7.10, P7.13 (PB4), P8.13 (PB4), P9.13 (PB4), P10.13 (PB4), P11.13 (PB4), P12.13 (PB4), P14.13 (PB4)
/PB5: J7.12, P7.16 (PB5), P8.16 (PB5), P9.16 (PB5), P10.16 (PB5), P11.16 (PB5), P12.16 (PB5), P14.16 (PB5)
/PB7: J7.18, P7.15 (PB7), P8.15 (PB7), P9.15 (PB7), P10.15 (PB7), P11.15 (PB7), P12.15 (PB7), P14.15 (PB7)
/PIN_2: P1.2 (PIN_2), P2.2 (PIN_2), P3.2 (PIN_2), P4.2 (PIN_2), P5.2 (PIN_2)
/PIN_3: P1.3 (PIN_3), P2.3 (PIN_3), P3.3 (PIN_3), P4.3 (PIN_3), P5.3 (PIN_3)
/PIN_16: P1.16 (PIN_16), P2.16 (PIN_16), P3.16 (PIN_16), P4.16 (PIN_16), P5.16 (PIN_16)
/PIN_17: P1.17 (PIN_17), P2.17 (PIN_17), P3.17 (PIN_17), P4.17 (PIN_17), P5.17 (PIN_17)
/PLL: P6.X (PLL), P13.X (PLL)
/PTR: J7.16, P7.U (PTR), P8.U (PTR), P9.U (PTR), P10.U (PTR), P11.U (PTR), P12.U (PTR), P14.U (PTR)
/PTR_R: P7.S (PTR_R), P8.S (PTR_R), P9.S (PTR_R), P10.S (PTR_R), P11.S (PTR_R), P12.S (PTR_R), P14.S (PTR_R)
/RAMRW: P6.Z (RAMRW), U3.4 (A2)
/RO: P6.5 (R0), RN5.5 (R4), U5.10
/ROW0: P7.17 (ROW0), P8.17 (ROW0), P9.17 (ROW0), P10.17 (ROW0), P11.17 (ROW0), P12.17 (ROW0), P14.17 (ROW0)
/ROW1: P7.Z (ROW1), P8.Z (ROW1), P9.Z (ROW1), P10.Z (ROW1), P11.Z (ROW1), P12.Z (ROW1), P14.Z (ROW1)
/ROW2: P7.X (ROW2), P8.X (ROW2), P9.X (ROW2), P10.X (ROW2), P11.X (ROW2), P12.X (ROW2), P14.X (ROW2)
/ROW3: J7.17, P7.V (ROW3), P8.V (ROW3), P9.V (ROW3), P10.V (ROW3), P11.V (ROW3), P12.V (ROW3), P14.V (ROW3)
/R/~W: P6.V (R/~W), U3.7 (A5)
/SST: P6.17 (SST), P13.17 (SST)
/SYNC: P6.1 (SYNC), U1.9 (A7)
/~BIRQ: P1.4 (~IRQ), P2.4 (~IRQ), P3.4 (~IRQ), P4.4 (~IRQ), P5.4 (~IRQ), P13.4 (~IRQ), RN5.6 (R5), U5.9
/~BNMI: P1.6 (~NMI), P2.6 (~NMI), P3.6 (~NMI), P4.6 (~NMI), P5.6 (~NMI), P13.6 (~NMI), RN5.2 (R1), U5.13
/~IRQ: P6.4 (~IRQ), U5.8
/~NMI: P6.6 (~NMI), U5.12
/~RDY: P6.2 (~RDY), P13.2 (~RDY)
/~RES: J8.1, P1.7 (~RES), P2.7 (~RES), P3.7 (~RES), P4.7 (~RES), P5.7 (~RES), P6.7 (~RES), P13.7 (~RES)
/~R/W: P6.W (~R/W), U3.6 (A4), U4.1 (A->B)
/~Ø2: P6.Y (~Ø2), U3.5 (A3)
/Ø1: P6.3 (Ø1), P13.3 (Ø1)
/Ø2: P6.U (Ø2), U3.8 (A6)
GND: C1.2, C2.2, C3.2, C4.2, C5.2, C6.1, C7.1, C8.1, C9.1, C10.2, C11.2, C12.2, C13.2, C14.2, C15.2, C16.2, C17.2, C18.2, C19.2, C20.2, C21.2, C22.2, C23.2, C24.2, C25.2, C26.2, C27.2, C28.2, C29.2, C30.2, C31.2, C32.2, C33.2, C34.2, C35.2, C36.2, C37.2, C38.2, C39.2, C40.2, C41.2, C42.2, C43.2, C44.2, C45.2, C46.2, C47.2, C48.2, C49.2, C50.2, C51.2, C52.2, C53.2, C54.2, C55.2, C56.2, C57.2, C58.2, C59.2, C60.2, C61.2, C62.2, C63.2, C64.2, J1.3, J2.S, J3.S, J6.3, J7.21, J7.22, J9.1, P1.22 (GND), P2.22 (GND), P3.22 (GND), P4.22 (GND), P5.22 (GND), P6.22 (GND), P7.1 (GND), P8.1 (GND), P9.1 (GND), P10.1 (GND), P11.1 (GND), P12.1 (GND), P13.22 (GND), P14.1 (GND), R1.1, R2.2, U1.1 (G1), U1.10 (GND), U1.19 (G2), U2.1 (G1), U2.10 (GND), U2.19 (G2), U3.1 (G1), U3.2 (A0), U3.3 (A1), U3.10 (GND), U3.19 (G2), U4.10 (GND), U5.1, U5.3, U5.5, U5.7 (GND), U6.1, U6.2, U6.4, U6.5, U6.7 (GND), U6.12, U6.13
unnamed: D1.1 (K), R1.2
unnamed: D2.1 (K), R2.1
unnamed: J2.T, J4.2
unnamed: J11.1, J13.2, P4.19 (~VECTOR_FETCH)
unnamed: J12.1, J14.2, P4.20 (~DECODE_ENABLE)
unnamed: J6.1, J12.2, P5.20 (~DECODE_ENABLE)
unnamed: RN1.1 (R1.1), U1.18 (Y0)
unnamed: RN1.2 (R2.1), U1.17 (Y1)
unnamed: RN1.3 (R3.1), U1.16 (Y2)
unnamed: RN1.4 (R4.1), U1.15 (Y3)
unnamed: RN1.5 (R5.1), U1.14 (Y4)
unnamed: RN1.6 (R6.1), U1.13 (Y5)
unnamed: RN1.7 (R7.1), U1.12 (Y6)
unnamed: RN1.8 (R8.1), U1.11 (Y7)
unnamed: RN2.1 (R1.1), U2.18 (Y0)
unnamed: RN2.2 (R2.1), U2.17 (Y1)
unnamed: RN2.3 (R3.1), U2.16 (Y2)
unnamed: RN2.4 (R4.1), U2.15 (Y3)
unnamed: RN2.5 (R5.1), U2.14 (Y4)
unnamed: RN2.6 (R6.1), U2.13 (Y5)
unnamed: RN2.7 (R7.1), U2.12 (Y6)
unnamed: RN2.8 (R8.1), U2.11 (Y7)
unnamed: RN3.3 (R3.1), U3.16 (Y2)
unnamed: RN3.4 (R4.1), U3.15 (Y3)
unnamed: RN3.5 (R5.1), U3.14 (Y4)
unnamed: RN3.6 (R6.1), U3.13 (Y5)
unnamed: RN3.7 (R7.1), U3.12 (Y6)
unnamed: RN3.8 (R8.1), U3.11 (Y7)
unnamed: RN4.1 (R1.1), U4.18 (B0)
unnamed: RN4.2 (R2.1), U4.17 (B1)
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

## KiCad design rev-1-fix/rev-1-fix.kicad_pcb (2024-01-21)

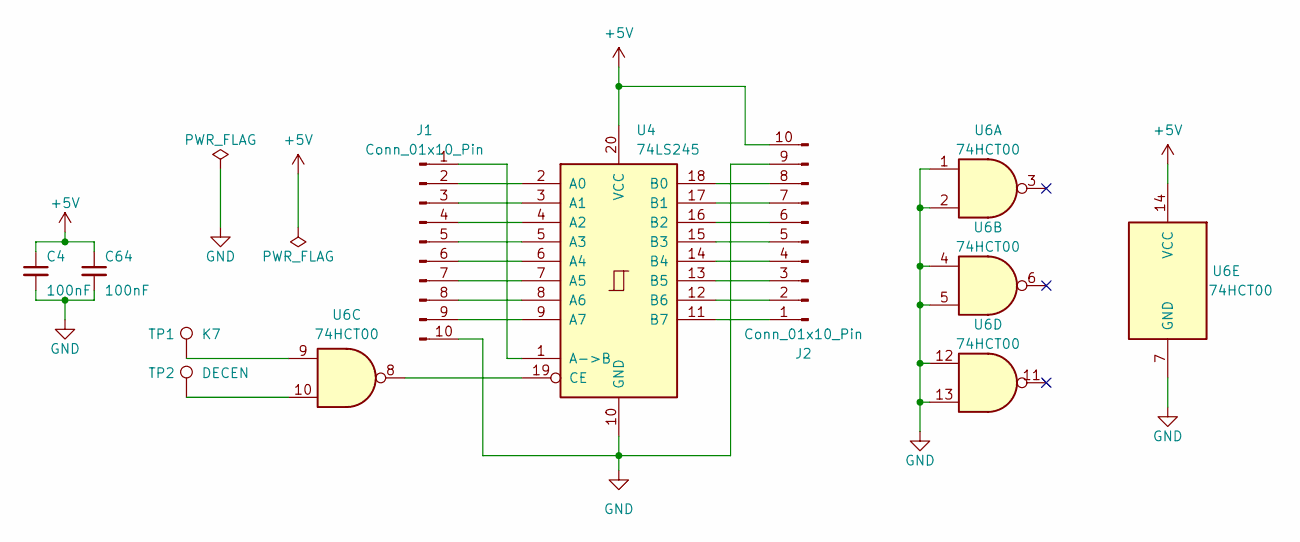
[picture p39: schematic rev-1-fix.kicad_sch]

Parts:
C4, C64: 100nF; C_Disc_D5.0mm_W2.5mm_P5.00mm
J1, J2: Conn_01x10_Pin; PinHeader_1x10_P2.54mm_Vertical
TP1: K7; TestPoint_THTPad_D1.5mm_Drill0.7mm
TP2: DECEN; TestPoint_THTPad_D1.5mm_Drill0.7mm
U4: 74LS245; DIP-20_W7.62mm_LongPads
U6: 74HCT00; DIP-14_W7.62mm_LongPads

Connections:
+5V: C4.1, C64.1, J2.10, U4.20 (VCC), U6.14 (VCC)
GND: C4.2, C64.2, J1.10, J2.9, U4.10 (GND), U6.1, U6.2, U6.4, U6.5, U6.7 (GND), U6.12, U6.13
unnamed: J1.1, U4.1 (A->B)
unnamed: J1.2, U4.2 (A0)
unnamed: J1.3, U4.3 (A1)
unnamed: J1.4, U4.4 (A2)
unnamed: J1.5, U4.5 (A3)
unnamed: J1.6, U4.6 (A4)
unnamed: J1.7, U4.7 (A5)
unnamed: J1.8, U4.8 (A6)
unnamed: J1.9, U4.9 (A7)
unnamed: J2.1, U4.11 (B7)
unnamed: J2.2, U4.12 (B6)
unnamed: J2.3, U4.13 (B5)
unnamed: J2.4, U4.14 (B4)
unnamed: J2.5, U4.15 (B3)
unnamed: J2.6, U4.16 (B2)
unnamed: J2.7, U4.17 (B1)
unnamed: J2.8, U4.18 (B0)
unnamed: TP1.1, U6.9
unnamed: TP2.1, U6.10
unnamed: U4.19 (CE), U6.8

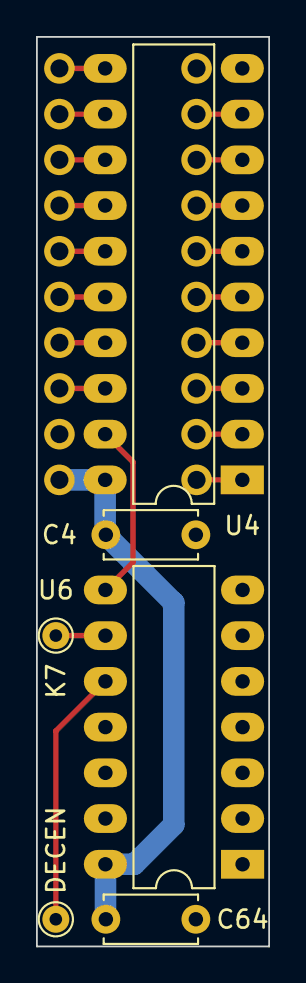
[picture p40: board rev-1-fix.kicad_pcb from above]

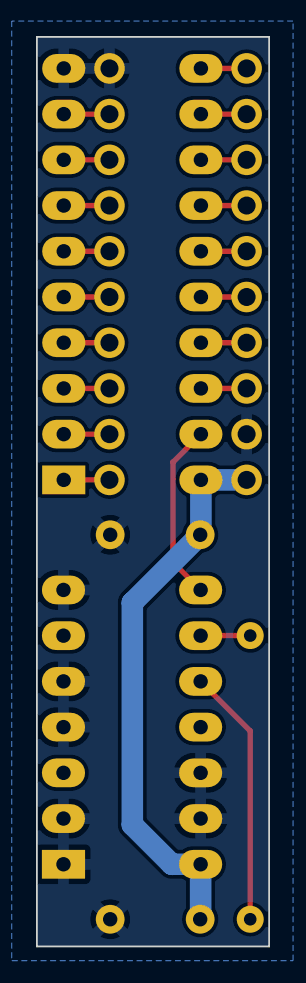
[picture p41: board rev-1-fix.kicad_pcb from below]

Board: 2 copper layers, 12.9 x 50.5 mm, 8 parts (2 on the bottom side), 22 nets.

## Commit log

2024-01-02 Disable data bus transceiver when DECEN or K7 active (low). Should fix issue #2
    [kim-1-mtu-motherboard-B_Cu.gbr, kim-1-mtu-motherboard-B_Mask.gbr, kim-1-mtu-motherboard-B_Silkscreen.gbr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]
2024-01-21 Add fix for Rev. 1 boards
    [rev-1-fix-B_Cu.gbr, rev-1-fix-B_Mask.gbr, rev-1-fix-Edge_Cuts.gbr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]
2024-01-21 Minor silkscreen fix
    [kim-1-mtu-motherboard.kicad_pcb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]
2024-02-17 Support Commodore-style DIN-6 connectors
2024-02-17 Revision 3. Fixes Issue #3
    [DS1040-02 (DIP_switch) blue.stp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]
2024-10-03 New auxiliary board for telnet over wifi terminal
    [4607x.stp, Abstandzbolzen Stahl verzinkt I-A M2.5_-_Ettinger - 5.12.141 (M2,5x14).stp, DIN 45322 C64 IEC serial port.step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]
2024-10-03 Minor trace optimizations
    [kim-1-aux-card-esp.kicad_pcb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]

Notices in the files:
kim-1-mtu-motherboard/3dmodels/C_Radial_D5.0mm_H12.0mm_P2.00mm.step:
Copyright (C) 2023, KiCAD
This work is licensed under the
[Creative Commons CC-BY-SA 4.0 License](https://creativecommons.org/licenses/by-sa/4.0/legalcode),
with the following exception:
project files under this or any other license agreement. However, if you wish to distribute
